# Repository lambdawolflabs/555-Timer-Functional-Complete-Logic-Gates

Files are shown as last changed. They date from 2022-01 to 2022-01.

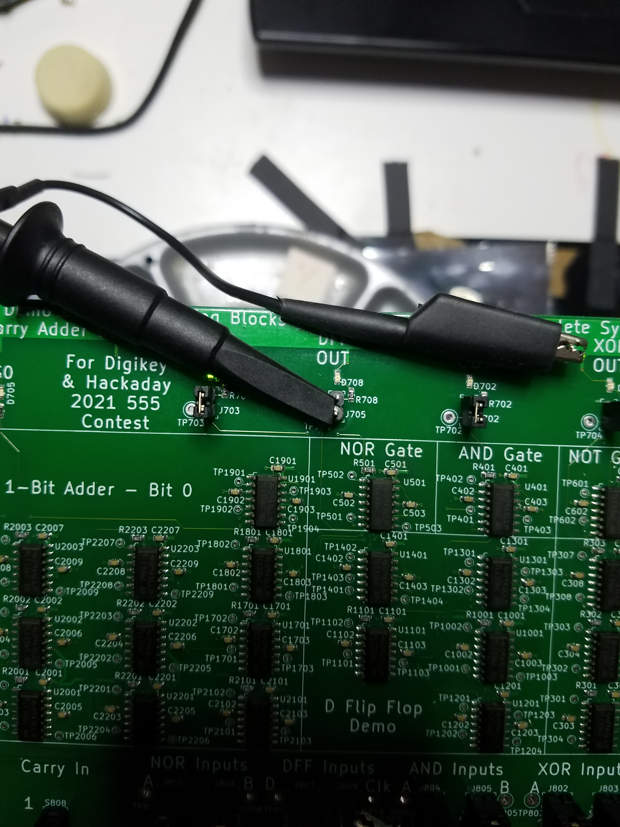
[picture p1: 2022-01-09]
Photos/DFF_PropTest_Setup_Output_20220109_155419.jpg

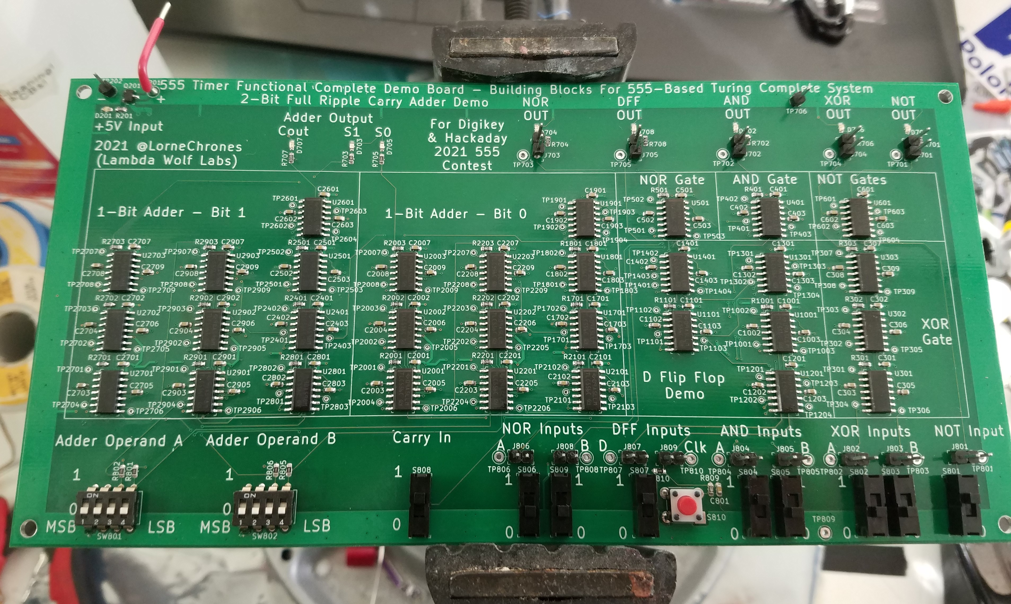
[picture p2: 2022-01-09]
Photos/Assembled_Board_Overview_Top_20220109_130825.jpg

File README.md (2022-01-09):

# 555-Timer-Functional-Complete-Logic-Gates

Hackaday IO Project Link Here (More details there): https://hackaday.io/project/183516 

For 2021/2022 Hackaday/Digikey 555 Timer Contest: https://hackaday.io/contest/182830-555-timer-contest

**
Overview:**
Purpose: 2 bit ripple-carry adder using nothing but 556s timer chips ( 2bits x (2 XORs + 2 ANDs + 1 OR = 6 + 6 + 2 + 2 + 3) ) = 38 555s or 19 556s. Inputs being dip switches and the outputs being LEDs. 

	A couple of spare 555s for demonstrating various gates individually:
		NOT - 1 555
		AND - 2 555
		NOR - 2 555
		XOR - 6 555
		D Flip Flop (Safe, not edge triggered)    -   Requires 7 555s?

Specs:

	-Room Temp Operation (25C +/-10C)
	-5VDC Operation (~180mA peak)
	-Powered by bench power supply with binding posts or hooks (reverse protection MOSFET included)
	-NO explicit ESD protection.

Logic Gate Ports:

	<FUNC>_<CMOS or NMOS>_<IN or OUT>_<Boolean Identifier: A B or Y or Q  or Abar  or  Bbar>   
	
	e.g.  AND_CMOS_IN_A   or    INV_CMOS_OUT_ABAR    or   A0_CMOS_IN
	Q is saved for Flip Flops, Y is saved for logic gates

Switches Ports:

	<FUNC>_<PD or PU or CMOS>_<SW or PB>

	e.g. A2_PD_SW  or  Carry_CMOS_SW  or AND_Demo_A_CMOS_SW

LED Ports:

	<FUNC>_<ActiveHigh or ActiveLow>_LED

	e.g. S3_ActiveHigh_LED

Labels:

	For highest level net name:  <FUNC>_Root  e.g. S0_Root  or Cout_Root

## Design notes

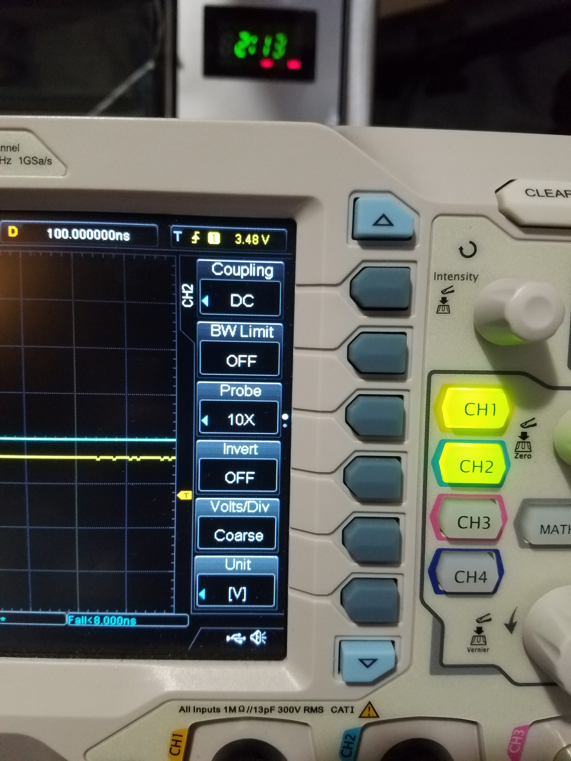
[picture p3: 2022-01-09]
Photos/ScopeChBSettings_20220109_153201.jpg

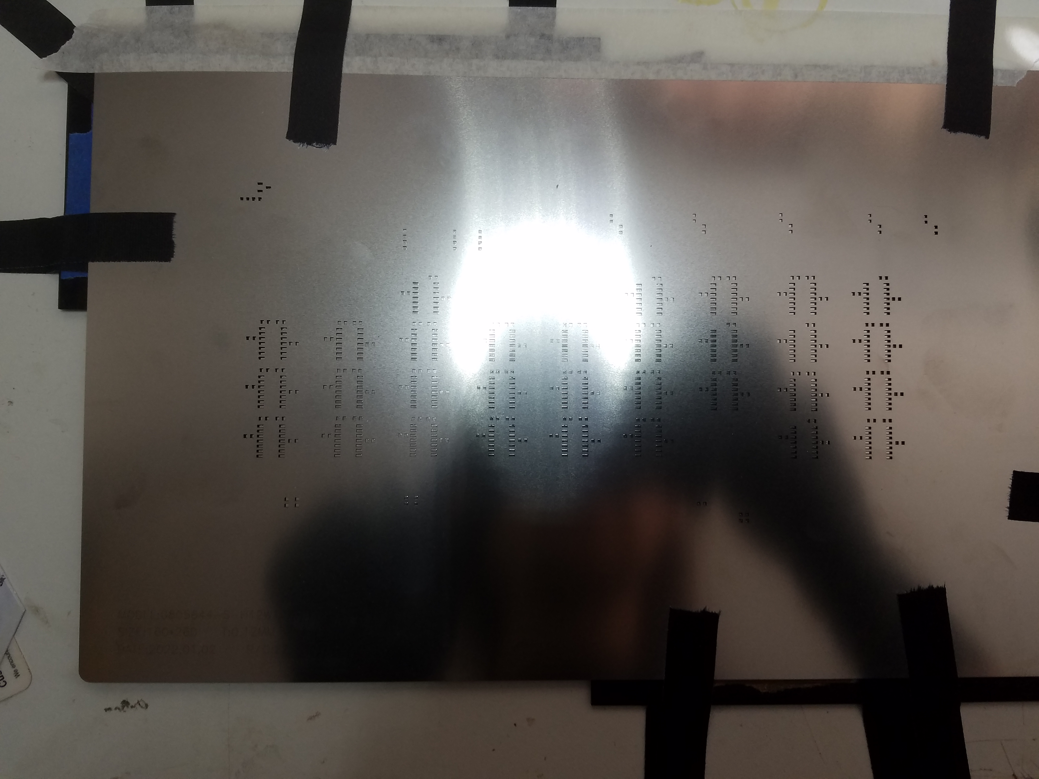
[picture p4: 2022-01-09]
Photos/ReadyForPaste_20220108_125551.jpg

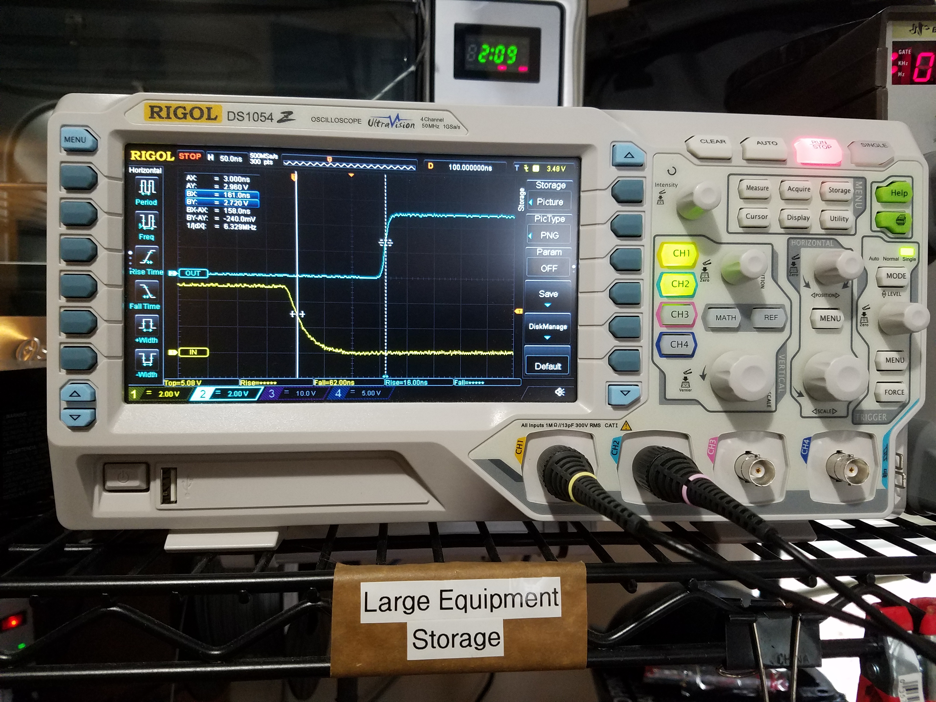
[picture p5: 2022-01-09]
Photos/Oscope_Used_20220109_152751.jpg

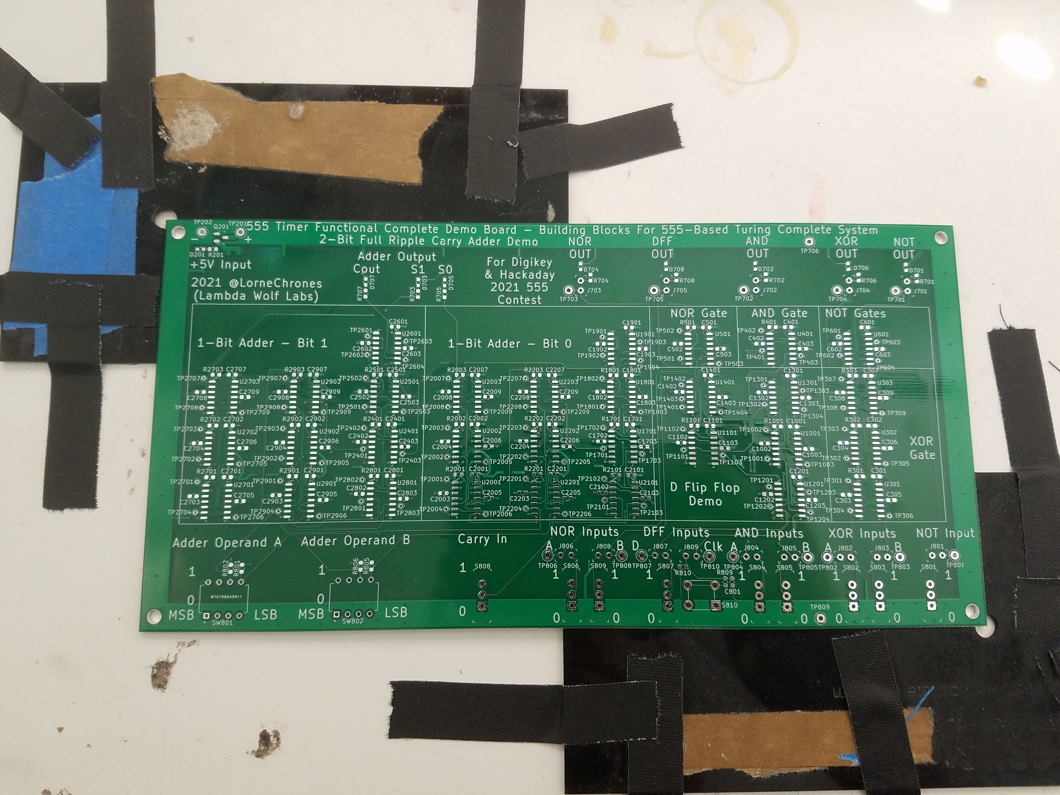
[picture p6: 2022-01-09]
Photos/BareBoard_20220108_125135.jpg

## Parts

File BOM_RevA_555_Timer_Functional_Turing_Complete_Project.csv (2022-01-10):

BOM/Design Name: | 555 Timer Functional Complete For Turing Machine Project
Drawing Number: | "/> 3
Revision: | A
Company: | Lambda Wolf Lab (Lorne Chrones)
Date: | 12/30/2021 5:45:50 PM
Tool: | Eeschema (5.1.2)-2
Populated Component Count: | 201
Number of DNP Components: | 0
Line Item | Ref | Qty | Value | Footprint | MPN | Manufacturer | Description | Datasheet | Vendor
1 | C301 | 1 | CL10B104KB8NNNL | Capacitor_SMD:C_0603_1608Metric | CL10B104KB8NNNL | Samsung Electro-Mechanics | CAP CER 0.1UF 50V X7R 0603 | http://www.samsungsem.com/kr/support/product-search/mlcc/CL10B104KB8NNNL.jsp
1 | C302 | 1 | CL10B104KB8NNNL | Capacitor_SMD:C_0603_1608Metric | CL10B104KB8NNNL | Samsung Electro-Mechanics | CAP CER 0.1UF 50V X7R 0603 | http://www.samsungsem.com/kr/support/product-search/mlcc/CL10B104KB8NNNL.jsp
1 | C303 | 1 | CL10B104KB8NNNL | Capacitor_SMD:C_0603_1608Metric | CL10B104KB8NNNL | Samsung Electro-Mechanics | CAP CER 0.1UF 50V X7R 0603 | http://www.samsungsem.com/kr/support/product-search/mlcc/CL10B104KB8NNNL.jsp
1 | C304 | 1 | CL10B104KB8NNNL | Capacitor_SMD:C_0603_1608Metric | CL10B104KB8NNNL | Samsung Electro-Mechanics | CAP CER 0.1UF 50V X7R 0603 | http://www.samsungsem.com/kr/support/product-search/mlcc/CL10B104KB8NNNL.jsp
1 | C305 | 1 | CL10B104KB8NNNL | Capacitor_SMD:C_0603_1608Metric | CL10B104KB8NNNL | Samsung Electro-Mechanics | CAP CER 0.1UF 50V X7R 0603 | http://www.samsungsem.com/kr/support/product-search/mlcc/CL10B104KB8NNNL.jsp
1 | C306 | 1 | CL10B104KB8NNNL | Capacitor_SMD:C_0603_1608Metric | CL10B104KB8NNNL | Samsung Electro-Mechanics | CAP CER 0.1UF 50V X7R 0603 | http://www.samsungsem.com/kr/support/product-search/mlcc/CL10B104KB8NNNL.jsp
1 | C307 | 1 | CL10B104KB8NNNL | Capacitor_SMD:C_0603_1608Metric | CL10B104KB8NNNL | Samsung Electro-Mechanics | CAP CER 0.1UF 50V X7R 0603 | http://www.samsungsem.com/kr/support/product-search/mlcc/CL10B104KB8NNNL.jsp
1 | C308 | 1 | CL10B104KB8NNNL | Capacitor_SMD:C_0603_1608Metric | CL10B104KB8NNNL | Samsung Electro-Mechanics | CAP CER 0.1UF 50V X7R 0603 | http://www.samsungsem.com/kr/support/product-search/mlcc/CL10B104KB8NNNL.jsp
1 | C309 | 1 | CL10B104KB8NNNL | Capacitor_SMD:C_0603_1608Metric | CL10B104KB8NNNL | Samsung Electro-Mechanics | CAP CER 0.1UF 50V X7R 0603 | http://www.samsungsem.com/kr/support/product-search/mlcc/CL10B104KB8NNNL.jsp
1 | C401 | 1 | CL10B104KB8NNNL | Capacitor_SMD:C_0603_1608Metric | CL10B104KB8NNNL | Samsung Electro-Mechanics | CAP CER 0.1UF 50V X7R 0603 | http://www.samsungsem.com/kr/support/product-search/mlcc/CL10B104KB8NNNL.jsp
1 | C402 | 1 | CL10B104KB8NNNL | Capacitor_SMD:C_0603_1608Metric | CL10B104KB8NNNL | Samsung Electro-Mechanics | CAP CER 0.1UF 50V X7R 0603 | http://www.samsungsem.com/kr/support/product-search/mlcc/CL10B104KB8NNNL.jsp
1 | C403 | 1 | CL10B104KB8NNNL | Capacitor_SMD:C_0603_1608Metric | CL10B104KB8NNNL | Samsung Electro-Mechanics | CAP CER 0.1UF 50V X7R 0603 | http://www.samsungsem.com/kr/support/product-search/mlcc/CL10B104KB8NNNL.jsp
1 | C501 | 1 | CL10B104KB8NNNL | Capacitor_SMD:C_0603_1608Metric | CL10B104KB8NNNL | Samsung Electro-Mechanics | CAP CER 0.1UF 50V X7R 0603 | http://www.samsungsem.com/kr/support/product-search/mlcc/CL10B104KB8NNNL.jsp
1 | C502 | 1 | CL10B104KB8NNNL | Capacitor_SMD:C_0603_1608Metric | CL10B104KB8NNNL | Samsung Electro-Mechanics | CAP CER 0.1UF 50V X7R 0603 | http://www.samsungsem.com/kr/support/product-search/mlcc/CL10B104KB8NNNL.jsp
1 | C503 | 1 | CL10B104KB8NNNL | Capacitor_SMD:C_0603_1608Metric | CL10B104KB8NNNL | Samsung Electro-Mechanics | CAP CER 0.1UF 50V X7R 0603 | http://www.samsungsem.com/kr/support/product-search/mlcc/CL10B104KB8NNNL.jsp
1 | C601 | 1 | CL10B104KB8NNNL | Capacitor_SMD:C_0603_1608Metric | CL10B104KB8NNNL | Samsung Electro-Mechanics | CAP CER 0.1UF 50V X7R 0603 | http://www.samsungsem.com/kr/support/product-search/mlcc/CL10B104KB8NNNL.jsp
1 | C602 | 1 | CL10B104KB8NNNL | Capacitor_SMD:C_0603_1608Metric | CL10B104KB8NNNL | Samsung Electro-Mechanics | CAP CER 0.1UF 50V X7R 0603 | http://www.samsungsem.com/kr/support/product-search/mlcc/CL10B104KB8NNNL.jsp
1 | C603 | 1 | CL10B104KB8NNNL | Capacitor_SMD:C_0603_1608Metric | CL10B104KB8NNNL | Samsung Electro-Mechanics | CAP CER 0.1UF 50V X7R 0603 | http://www.samsungsem.com/kr/support/product-search/mlcc/CL10B104KB8NNNL.jsp
1 | C801 | 1 | CL10B104KB8NNNL | Capacitor_SMD:C_0603_1608Metric | CL10B104KB8NNNL | Samsung Electro-Mechanics | CAP CER 0.1UF 50V X7R 0603 | http://www.samsungsem.com/kr/support/product-search/mlcc/CL10B104KB8NNNL.jsp
1 | C1001 | 1 | CL10B104KB8NNNL | Capacitor_SMD:C_0603_1608Metric | CL10B104KB8NNNL | Samsung Electro-Mechanics | CAP CER 0.1UF 50V X7R 0603 | http://www.samsungsem.com/kr/support/product-search/mlcc/CL10B104KB8NNNL.jsp
1 | C1002 | 1 | CL10B104KB8NNNL | Capacitor_SMD:C_0603_1608Metric | CL10B104KB8NNNL | Samsung Electro-Mechanics | CAP CER 0.1UF 50V X7R 0603 | http://www.samsungsem.com/kr/support/product-search/mlcc/CL10B104KB8NNNL.jsp
1 | C1003 | 1 | CL10B104KB8NNNL | Capacitor_SMD:C_0603_1608Metric | CL10B104KB8NNNL | Samsung Electro-Mechanics | CAP CER 0.1UF 50V X7R 0603 | http://www.samsungsem.com/kr/support/product-search/mlcc/CL10B104KB8NNNL.jsp
1 | C1101 | 1 | CL10B104KB8NNNL | Capacitor_SMD:C_0603_1608Metric | CL10B104KB8NNNL | Samsung Electro-Mechanics | CAP CER 0.1UF 50V X7R 0603 | http://www.samsungsem.com/kr/support/product-search/mlcc/CL10B104KB8NNNL.jsp
1 | C1102 | 1 | CL10B104KB8NNNL | Capacitor_SMD:C_0603_1608Metric | CL10B104KB8NNNL | Samsung Electro-Mechanics | CAP CER 0.1UF 50V X7R 0603 | http://www.samsungsem.com/kr/support/product-search/mlcc/CL10B104KB8NNNL.jsp
1 | C1103 | 1 | CL10B104KB8NNNL | Capacitor_SMD:C_0603_1608Metric | CL10B104KB8NNNL | Samsung Electro-Mechanics | CAP CER 0.1UF 50V X7R 0603 | http://www.samsungsem.com/kr/support/product-search/mlcc/CL10B104KB8NNNL.jsp
1 | C1201 | 1 | CL10B104KB8NNNL | Capacitor_SMD:C_0603_1608Metric | CL10B104KB8NNNL | Samsung Electro-Mechanics | CAP CER 0.1UF 50V X7R 0603 | http://www.samsungsem.com/kr/support/product-search/mlcc/CL10B104KB8NNNL.jsp
1 | C1202 | 1 | CL10B104KB8NNNL | Capacitor_SMD:C_0603_1608Metric | CL10B104KB8NNNL | Samsung Electro-Mechanics | CAP CER 0.1UF 50V X7R 0603 | http://www.samsungsem.com/kr/support/product-search/mlcc/CL10B104KB8NNNL.jsp
1 | C1203 | 1 | CL10B104KB8NNNL | Capacitor_SMD:C_0603_1608Metric | CL10B104KB8NNNL | Samsung Electro-Mechanics | CAP CER 0.1UF 50V X7R 0603 | http://www.samsungsem.com/kr/support/product-search/mlcc/CL10B104KB8NNNL.jsp
1 | C1301 | 1 | CL10B104KB8NNNL | Capacitor_SMD:C_0603_1608Metric | CL10B104KB8NNNL | Samsung Electro-Mechanics | CAP CER 0.1UF 50V X7R 0603 | http://www.samsungsem.com/kr/support/product-search/mlcc/CL10B104KB8NNNL.jsp
1 | C1302 | 1 | CL10B104KB8NNNL | Capacitor_SMD:C_0603_1608Metric | CL10B104KB8NNNL | Samsung Electro-Mechanics | CAP CER 0.1UF 50V X7R 0603 | http://www.samsungsem.com/kr/support/product-search/mlcc/CL10B104KB8NNNL.jsp
1 | C1303 | 1 | CL10B104KB8NNNL | Capacitor_SMD:C_0603_1608Metric | CL10B104KB8NNNL | Samsung Electro-Mechanics | CAP CER 0.1UF 50V X7R 0603 | http://www.samsungsem.com/kr/support/product-search/mlcc/CL10B104KB8NNNL.jsp
1 | C1401 | 1 | CL10B104KB8NNNL | Capacitor_SMD:C_0603_1608Metric | CL10B104KB8NNNL | Samsung Electro-Mechanics | CAP CER 0.1UF 50V X7R 0603 | http://www.samsungsem.com/kr/support/product-search/mlcc/CL10B104KB8NNNL.jsp
1 | C1402 | 1 | CL10B104KB8NNNL | Capacitor_SMD:C_0603_1608Metric | CL10B104KB8NNNL | Samsung Electro-Mechanics | CAP CER 0.1UF 50V X7R 0603 | http://www.samsungsem.com/kr/support/product-search/mlcc/CL10B104KB8NNNL.jsp
1 | C1403 | 1 | CL10B104KB8NNNL | Capacitor_SMD:C_0603_1608Metric | CL10B104KB8NNNL | Samsung Electro-Mechanics | CAP CER 0.1UF 50V X7R 0603 | http://www.samsungsem.com/kr/support/product-search/mlcc/CL10B104KB8NNNL.jsp
1 | C1701 | 1 | CL10B104KB8NNNL | Capacitor_SMD:C_0603_1608Metric | CL10B104KB8NNNL | Samsung Electro-Mechanics | CAP CER 0.1UF 50V X7R 0603 | http://www.samsungsem.com/kr/support/product-search/mlcc/CL10B104KB8NNNL.jsp
1 | C1702 | 1 | CL10B104KB8NNNL | Capacitor_SMD:C_0603_1608Metric | CL10B104KB8NNNL | Samsung Electro-Mechanics | CAP CER 0.1UF 50V X7R 0603 | http://www.samsungsem.com/kr/support/product-search/mlcc/CL10B104KB8NNNL.jsp
1 | C1703 | 1 | CL10B104KB8NNNL | Capacitor_SMD:C_0603_1608Metric | CL10B104KB8NNNL | Samsung Electro-Mechanics | CAP CER 0.1UF 50V X7R 0603 | http://www.samsungsem.com/kr/support/product-search/mlcc/CL10B104KB8NNNL.jsp
1 | C1801 | 1 | CL10B104KB8NNNL | Capacitor_SMD:C_0603_1608Metric | CL10B104KB8NNNL | Samsung Electro-Mechanics | CAP CER 0.1UF 50V X7R 0603 | http://www.samsungsem.com/kr/support/product-search/mlcc/CL10B104KB8NNNL.jsp
1 | C1802 | 1 | CL10B104KB8NNNL | Capacitor_SMD:C_0603_1608Metric | CL10B104KB8NNNL | Samsung Electro-Mechanics | CAP CER 0.1UF 50V X7R 0603 | http://www.samsungsem.com/kr/support/product-search/mlcc/CL10B104KB8NNNL.jsp
1 | C1803 | 1 | CL10B104KB8NNNL | Capacitor_SMD:C_0603_1608Metric | CL10B104KB8NNNL | Samsung Electro-Mechanics | CAP CER 0.1UF 50V X7R 0603 | http://www.samsungsem.com/kr/support/product-search/mlcc/CL10B104KB8NNNL.jsp
1 | C1901 | 1 | CL10B104KB8NNNL | Capacitor_SMD:C_0603_1608Metric | CL10B104KB8NNNL | Samsung Electro-Mechanics | CAP CER 0.1UF 50V X7R 0603 | http://www.samsungsem.com/kr/support/product-search/mlcc/CL10B104KB8NNNL.jsp
1 | C1902 | 1 | CL10B104KB8NNNL | Capacitor_SMD:C_0603_1608Metric | CL10B104KB8NNNL | Samsung Electro-Mechanics | CAP CER 0.1UF 50V X7R 0603 | http://www.samsungsem.com/kr/support/product-search/mlcc/CL10B104KB8NNNL.jsp
1 | C1903 | 1 | CL10B104KB8NNNL | Capacitor_SMD:C_0603_1608Metric | CL10B104KB8NNNL | Samsung Electro-Mechanics | CAP CER 0.1UF 50V X7R 0603 | http://www.samsungsem.com/kr/support/product-search/mlcc/CL10B104KB8NNNL.jsp
1 | C2001 | 1 | CL10B104KB8NNNL | Capacitor_SMD:C_0603_1608Metric | CL10B104KB8NNNL | Samsung Electro-Mechanics | CAP CER 0.1UF 50V X7R 0603 | http://www.samsungsem.com/kr/support/product-search/mlcc/CL10B104KB8NNNL.jsp
1 | C2002 | 1 | CL10B104KB8NNNL | Capacitor_SMD:C_0603_1608Metric | CL10B104KB8NNNL | Samsung Electro-Mechanics | CAP CER 0.1UF 50V X7R 0603 | http://www.samsungsem.com/kr/support/product-search/mlcc/CL10B104KB8NNNL.jsp
1 | C2003 | 1 | CL10B104KB8NNNL | Capacitor_SMD:C_0603_1608Metric | CL10B104KB8NNNL | Samsung Electro-Mechanics | CAP CER 0.1UF 50V X7R 0603 | http://www.samsungsem.com/kr/support/product-search/mlcc/CL10B104KB8NNNL.jsp
1 | C2004 | 1 | CL10B104KB8NNNL | Capacitor_SMD:C_0603_1608Metric | CL10B104KB8NNNL | Samsung Electro-Mechanics | CAP CER 0.1UF 50V X7R 0603 | http://www.samsungsem.com/kr/support/product-search/mlcc/CL10B104KB8NNNL.jsp
1 | C2005 | 1 | CL10B104KB8NNNL | Capacitor_SMD:C_0603_1608Metric | CL10B104KB8NNNL | Samsung Electro-Mechanics | CAP CER 0.1UF 50V X7R 0603 | http://www.samsungsem.com/kr/support/product-search/mlcc/CL10B104KB8NNNL.jsp
1 | C2006 | 1 | CL10B104KB8NNNL | Capacitor_SMD:C_0603_1608Metric | CL10B104KB8NNNL | Samsung Electro-Mechanics | CAP CER 0.1UF 50V X7R 0603 | http://www.samsungsem.com/kr/support/product-search/mlcc/CL10B104KB8NNNL.jsp
1 | C2007 | 1 | CL10B104KB8NNNL | Capacitor_SMD:C_0603_1608Metric | CL10B104KB8NNNL | Samsung Electro-Mechanics | CAP CER 0.1UF 50V X7R 0603 | http://www.samsungsem.com/kr/support/product-search/mlcc/CL10B104KB8NNNL.jsp
1 | C2008 | 1 | CL10B104KB8NNNL | Capacitor_SMD:C_0603_1608Metric | CL10B104KB8NNNL | Samsung Electro-Mechanics | CAP CER 0.1UF 50V X7R 0603 | http://www.samsungsem.com/kr/support/product-search/mlcc/CL10B104KB8NNNL.jsp
1 | C2009 | 1 | CL10B104KB8NNNL | Capacitor_SMD:C_0603_1608Metric | CL10B104KB8NNNL | Samsung Electro-Mechanics | CAP CER 0.1UF 50V X7R 0603 | http://www.samsungsem.com/kr/support/product-search/mlcc/CL10B104KB8NNNL.jsp
1 | C2101 | 1 | CL10B104KB8NNNL | Capacitor_SMD:C_0603_1608Metric | CL10B104KB8NNNL | Samsung Electro-Mechanics | CAP CER 0.1UF 50V X7R 0603 | http://www.samsungsem.com/kr/support/product-search/mlcc/CL10B104KB8NNNL.jsp
1 | C2102 | 1 | CL10B104KB8NNNL | Capacitor_SMD:C_0603_1608Metric | CL10B104KB8NNNL | Samsung Electro-Mechanics | CAP CER 0.1UF 50V X7R 0603 | http://www.samsungsem.com/kr/support/product-search/mlcc/CL10B104KB8NNNL.jsp
1 | C2103 | 1 | CL10B104KB8NNNL | Capacitor_SMD:C_0603_1608Metric | CL10B104KB8NNNL | Samsung Electro-Mechanics | CAP CER 0.1UF 50V X7R 0603 | http://www.samsungsem.com/kr/support/product-search/mlcc/CL10B104KB8NNNL.jsp
1 | C2201 | 1 | CL10B104KB8NNNL | Capacitor_SMD:C_0603_1608Metric | CL10B104KB8NNNL | Samsung Electro-Mechanics | CAP CER 0.1UF 50V X7R 0603 | http://www.samsungsem.com/kr/support/product-search/mlcc/CL10B104KB8NNNL.jsp
1 | C2202 | 1 | CL10B104KB8NNNL | Capacitor_SMD:C_0603_1608Metric | CL10B104KB8NNNL | Samsung Electro-Mechanics | CAP CER 0.1UF 50V X7R 0603 | http://www.samsungsem.com/kr/support/product-search/mlcc/CL10B104KB8NNNL.jsp
1 | C2203 | 1 | CL10B104KB8NNNL | Capacitor_SMD:C_0603_1608Metric | CL10B104KB8NNNL | Samsung Electro-Mechanics | CAP CER 0.1UF 50V X7R 0603 | http://www.samsungsem.com/kr/support/product-search/mlcc/CL10B104KB8NNNL.jsp
1 | C2204 | 1 | CL10B104KB8NNNL | Capacitor_SMD:C_0603_1608Metric | CL10B104KB8NNNL | Samsung Electro-Mechanics | CAP CER 0.1UF 50V X7R 0603 | http://www.samsungsem.com/kr/support/product-search/mlcc/CL10B104KB8NNNL.jsp
1 | C2205 | 1 | CL10B104KB8NNNL | Capacitor_SMD:C_0603_1608Metric | CL10B104KB8NNNL | Samsung Electro-Mechanics | CAP CER 0.1UF 50V X7R 0603 | http://www.samsungsem.com/kr/support/product-search/mlcc/CL10B104KB8NNNL.jsp
1 | C2206 | 1 | CL10B104KB8NNNL | Capacitor_SMD:C_0603_1608Metric | CL10B104KB8NNNL | Samsung Electro-Mechanics | CAP CER 0.1UF 50V X7R 0603 | http://www.samsungsem.com/kr/support/product-search/mlcc/CL10B104KB8NNNL.jsp
1 | C2207 | 1 | CL10B104KB8NNNL | Capacitor_SMD:C_0603_1608Metric | CL10B104KB8NNNL | Samsung Electro-Mechanics | CAP CER 0.1UF 50V X7R 0603 | http://www.samsungsem.com/kr/support/product-search/mlcc/CL10B104KB8NNNL.jsp
1 | C2208 | 1 | CL10B104KB8NNNL | Capacitor_SMD:C_0603_1608Metric | CL10B104KB8NNNL | Samsung Electro-Mechanics | CAP CER 0.1UF 50V X7R 0603 | http://www.samsungsem.com/kr/support/product-search/mlcc/CL10B104KB8NNNL.jsp
1 | C2209 | 1 | CL10B104KB8NNNL | Capacitor_SMD:C_0603_1608Metric | CL10B104KB8NNNL | Samsung Electro-Mechanics | CAP CER 0.1UF 50V X7R 0603 | http://www.samsungsem.com/kr/support/product-search/mlcc/CL10B104KB8NNNL.jsp
1 | C2401 | 1 | CL10B104KB8NNNL | Capacitor_SMD:C_0603_1608Metric | CL10B104KB8NNNL | Samsung Electro-Mechanics | CAP CER 0.1UF 50V X7R 0603 | http://www.samsungsem.com/kr/support/product-search/mlcc/CL10B104KB8NNNL.jsp
1 | C2402 | 1 | CL10B104KB8NNNL | Capacitor_SMD:C_0603_1608Metric | CL10B104KB8NNNL | Samsung Electro-Mechanics | CAP CER 0.1UF 50V X7R 0603 | http://www.samsungsem.com/kr/support/product-search/mlcc/CL10B104KB8NNNL.jsp
1 | C2403 | 1 | CL10B104KB8NNNL | Capacitor_SMD:C_0603_1608Metric | CL10B104KB8NNNL | Samsung Electro-Mechanics | CAP CER 0.1UF 50V X7R 0603 | http://www.samsungsem.com/kr/support/product-search/mlcc/CL10B104KB8NNNL.jsp
1 | C2501 | 1 | CL10B104KB8NNNL | Capacitor_SMD:C_0603_1608Metric | CL10B104KB8NNNL | Samsung Electro-Mechanics | CAP CER 0.1UF 50V X7R 0603 | http://www.samsungsem.com/kr/support/product-search/mlcc/CL10B104KB8NNNL.jsp
1 | C2502 | 1 | CL10B104KB8NNNL | Capacitor_SMD:C_0603_1608Metric | CL10B104KB8NNNL | Samsung Electro-Mechanics | CAP CER 0.1UF 50V X7R 0603 | http://www.samsungsem.com/kr/support/product-search/mlcc/CL10B104KB8NNNL.jsp
1 | C2503 | 1 | CL10B104KB8NNNL | Capacitor_SMD:C_0603_1608Metric | CL10B104KB8NNNL | Samsung Electro-Mechanics | CAP CER 0.1UF 50V X7R 0603 | http://www.samsungsem.com/kr/support/product-search/mlcc/CL10B104KB8NNNL.jsp
1 | C2601 | 1 | CL10B104KB8NNNL | Capacitor_SMD:C_0603_1608Metric | CL10B104KB8NNNL | Samsung Electro-Mechanics | CAP CER 0.1UF 50V X7R 0603 | http://www.samsungsem.com/kr/support/product-search/mlcc/CL10B104KB8NNNL.jsp
1 | C2602 | 1 | CL10B104KB8NNNL | Capacitor_SMD:C_0603_1608Metric | CL10B104KB8NNNL | Samsung Electro-Mechanics | CAP CER 0.1UF 50V X7R 0603 | http://www.samsungsem.com/kr/support/product-search/mlcc/CL10B104KB8NNNL.jsp
1 | C2603 | 1 | CL10B104KB8NNNL | Capacitor_SMD:C_0603_1608Metric | CL10B104KB8NNNL | Samsung Electro-Mechanics | CAP CER 0.1UF 50V X7R 0603 | http://www.samsungsem.com/kr/support/product-search/mlcc/CL10B104KB8NNNL.jsp
1 | C2701 | 1 | CL10B104KB8NNNL | Capacitor_SMD:C_0603_1608Metric | CL10B104KB8NNNL | Samsung Electro-Mechanics | CAP CER 0.1UF 50V X7R 0603 | http://www.samsungsem.com/kr/support/product-search/mlcc/CL10B104KB8NNNL.jsp
1 | C2702 | 1 | CL10B104KB8NNNL | Capacitor_SMD:C_0603_1608Metric | CL10B104KB8NNNL | Samsung Electro-Mechanics | CAP CER 0.1UF 50V X7R 0603 | http://www.samsungsem.com/kr/support/product-search/mlcc/CL10B104KB8NNNL.jsp
1 | C2703 | 1 | CL10B104KB8NNNL | Capacitor_SMD:C_0603_1608Metric | CL10B104KB8NNNL | Samsung Electro-Mechanics | CAP CER 0.1UF 50V X7R 0603 | http://www.samsungsem.com/kr/support/product-search/mlcc/CL10B104KB8NNNL.jsp
1 | C2704 | 1 | CL10B104KB8NNNL | Capacitor_SMD:C_0603_1608Metric | CL10B104KB8NNNL | Samsung Electro-Mechanics | CAP CER 0.1UF 50V X7R 0603 | http://www.samsungsem.com/kr/support/product-search/mlcc/CL10B104KB8NNNL.jsp
1 | C2705 | 1 | CL10B104KB8NNNL | Capacitor_SMD:C_0603_1608Metric | CL10B104KB8NNNL | Samsung Electro-Mechanics | CAP CER 0.1UF 50V X7R 0603 | http://www.samsungsem.com/kr/support/product-search/mlcc/CL10B104KB8NNNL.jsp
1 | C2706 | 1 | CL10B104KB8NNNL | Capacitor_SMD:C_0603_1608Metric | CL10B104KB8NNNL | Samsung Electro-Mechanics | CAP CER 0.1UF 50V X7R 0603 | http://www.samsungsem.com/kr/support/product-search/mlcc/CL10B104KB8NNNL.jsp
1 | C2707 | 1 | CL10B104KB8NNNL | Capacitor_SMD:C_0603_1608Metric | CL10B104KB8NNNL | Samsung Electro-Mechanics | CAP CER 0.1UF 50V X7R 0603 | http://www.samsungsem.com/kr/support/product-search/mlcc/CL10B104KB8NNNL.jsp
1 | C2708 | 1 | CL10B104KB8NNNL | Capacitor_SMD:C_0603_1608Metric | CL10B104KB8NNNL | Samsung Electro-Mechanics | CAP CER 0.1UF 50V X7R 0603 | http://www.samsungsem.com/kr/support/product-search/mlcc/CL10B104KB8NNNL.jsp
1 | C2709 | 1 | CL10B104KB8NNNL | Capacitor_SMD:C_0603_1608Metric | CL10B104KB8NNNL | Samsung Electro-Mechanics | CAP CER 0.1UF 50V X7R 0603 | http://www.samsungsem.com/kr/support/product-search/mlcc/CL10B104KB8NNNL.jsp
1 | C2801 | 1 | CL10B104KB8NNNL | Capacitor_SMD:C_0603_1608Metric | CL10B104KB8NNNL | Samsung Electro-Mechanics | CAP CER 0.1UF 50V X7R 0603 | http://www.samsungsem.com/kr/support/product-search/mlcc/CL10B104KB8NNNL.jsp
1 | C2802 | 1 | CL10B104KB8NNNL | Capacitor_SMD:C_0603_1608Metric | CL10B104KB8NNNL | Samsung Electro-Mechanics | CAP CER 0.1UF 50V X7R 0603 | http://www.samsungsem.com/kr/support/product-search/mlcc/CL10B104KB8NNNL.jsp
1 | C2803 | 1 | CL10B104KB8NNNL | Capacitor_SMD:C_0603_1608Metric | CL10B104KB8NNNL | Samsung Electro-Mechanics | CAP CER 0.1UF 50V X7R 0603 | http://www.samsungsem.com/kr/support/product-search/mlcc/CL10B104KB8NNNL.jsp
1 | C2901 | 1 | CL10B104KB8NNNL | Capacitor_SMD:C_0603_1608Metric | CL10B104KB8NNNL | Samsung Electro-Mechanics | CAP CER 0.1UF 50V X7R 0603 | http://www.samsungsem.com/kr/support/product-search/mlcc/CL10B104KB8NNNL.jsp
1 | C2902 | 1 | CL10B104KB8NNNL | Capacitor_SMD:C_0603_1608Metric | CL10B104KB8NNNL | Samsung Electro-Mechanics | CAP CER 0.1UF 50V X7R 0603 | http://www.samsungsem.com/kr/support/product-search/mlcc/CL10B104KB8NNNL.jsp
1 | C2903 | 1 | CL10B104KB8NNNL | Capacitor_SMD:C_0603_1608Metric | CL10B104KB8NNNL | Samsung Electro-Mechanics | CAP CER 0.1UF 50V X7R 0603 | http://www.samsungsem.com/kr/support/product-search/mlcc/CL10B104KB8NNNL.jsp
1 | C2904 | 1 | CL10B104KB8NNNL | Capacitor_SMD:C_0603_1608Metric | CL10B104KB8NNNL | Samsung Electro-Mechanics | CAP CER 0.1UF 50V X7R 0603 | http://www.samsungsem.com/kr/support/product-search/mlcc/CL10B104KB8NNNL.jsp
1 | C2905 | 1 | CL10B104KB8NNNL | Capacitor_SMD:C_0603_1608Metric | CL10B104KB8NNNL | Samsung Electro-Mechanics | CAP CER 0.1UF 50V X7R 0603 | http://www.samsungsem.com/kr/support/product-search/mlcc/CL10B104KB8NNNL.jsp
1 | C2906 | 1 | CL10B104KB8NNNL | Capacitor_SMD:C_0603_1608Metric | CL10B104KB8NNNL | Samsung Electro-Mechanics | CAP CER 0.1UF 50V X7R 0603 | http://www.samsungsem.com/kr/support/product-search/mlcc/CL10B104KB8NNNL.jsp
1 | C2907 | 1 | CL10B104KB8NNNL | Capacitor_SMD:C_0603_1608Metric | CL10B104KB8NNNL | Samsung Electro-Mechanics | CAP CER 0.1UF 50V X7R 0603 | http://www.samsungsem.com/kr/support/product-search/mlcc/CL10B104KB8NNNL.jsp
1 | C2908 | 1 | CL10B104KB8NNNL | Capacitor_SMD:C_0603_1608Metric | CL10B104KB8NNNL | Samsung Electro-Mechanics | CAP CER 0.1UF 50V X7R 0603 | http://www.samsungsem.com/kr/support/product-search/mlcc/CL10B104KB8NNNL.jsp
1 | C2909 | 1 | CL10B104KB8NNNL | Capacitor_SMD:C_0603_1608Metric | CL10B104KB8NNNL | Samsung Electro-Mechanics | CAP CER 0.1UF 50V X7R 0603 | http://www.samsungsem.com/kr/support/product-search/mlcc/CL10B104KB8NNNL.jsp
95 | D201 | 1 | 150060RS75000 | digikey-footprints:LED_0603 | 150060RS75000 | Wurth Electronics Inc. | LED RED CLEAR 0603 SMD | https://katalog.we-online.de/led/datasheet/150060RS75000.pdf
96 | D701 | 1 | 150060VS75000 | digikey-footprints:LED_0603 | 150060VS75000 | Wurth Electronics Inc. | LED GREEN CLEAR 0603 SMD | https://katalog.we-online.de/led/datasheet/150060VS75000.pdf
96 | D702 | 1 | 150060VS75000 | digikey-footprints:LED_0603 | 150060VS75000 | Wurth Electronics Inc. | LED GREEN CLEAR 0603 SMD | https://katalog.we-online.de/led/datasheet/150060VS75000.pdf
98 | D703 | 1 | 150060BS75000 | digikey-footprints:LED_0603 | 150060BS75000 | Wurth Electronics Inc. | LED BLUE CLEAR 0603 SMD | https://katalog.we-online.de/led/datasheet/150060BS75000.pdf
96 | D704 | 1 | 150060VS75000 | digikey-footprints:LED_0603 | 150060VS75000 | Wurth Electronics Inc. | LED GREEN CLEAR 0603 SMD | https://katalog.we-online.de/led/datasheet/150060VS75000.pdf
98 | D705 | 1 | 150060BS75000 | digikey-footprints:LED_0603 | 150060BS75000 | Wurth Electronics Inc. | LED BLUE CLEAR 0603 SMD | https://katalog.we-online.de/led/datasheet/150060BS75000.pdf
96 | D706 | 1 | 150060VS75000 | digikey-footprints:LED_0603 | 150060VS75000 | Wurth Electronics Inc. | LED GREEN CLEAR 0603 SMD | https://katalog.we-online.de/led/datasheet/150060VS75000.pdf
102 | D707 | 1 | 150060YS75000 | digikey-footprints:LED_0603 | 150060YS75000 | Wurth Electronics Inc. | LED YELLOW CLEAR 0603 SMD | https://katalog.we-online.de/led/datasheet/150060YS75000.pdf
96 | D708 | 1 | 150060VS75000 | digikey-footprints:LED_0603 | 150060VS75000 | Wurth Electronics Inc. | LED GREEN CLEAR 0603 SMD | https://katalog.we-online.de/led/datasheet/150060VS75000.pdf
104 | J701 | 1 | M20-9990246 | digikey-footprints:PinHeader_1x2_P2.54mm | M20-9990246 | Harwin Inc. | CONN HEADER VERT 2POS 2.54MM | https://cdn.harwin.com/pdfs/M20-999.pdf
104 | J702 | 1 | M20-9990246 | digikey-footprints:PinHeader_1x2_P2.54mm | M20-9990246 | Harwin Inc. | CONN HEADER VERT 2POS 2.54MM | https://cdn.harwin.com/pdfs/M20-999.pdf
104 | J703 | 1 | M20-9990246 | digikey-footprints:PinHeader_1x2_P2.54mm | M20-9990246 | Harwin Inc. | CONN HEADER VERT 2POS 2.54MM | https://cdn.harwin.com/pdfs/M20-999.pdf
104 | J704 | 1 | M20-9990246 | digikey-footprints:PinHeader_1x2_P2.54mm | M20-9990246 | Harwin Inc. | CONN HEADER VERT 2POS 2.54MM | https://cdn.harwin.com/pdfs/M20-999.pdf
104 | J705 | 1 | M20-9990246 | digikey-footprints:PinHeader_1x2_P2.54mm | M20-9990246 | Harwin Inc. | CONN HEADER VERT 2POS 2.54MM | https://cdn.harwin.com/pdfs/M20-999.pdf
104 | J801 | 1 | M20-9990246 | digikey-footprints:PinHeader_1x2_P2.54mm | M20-9990246 | Harwin Inc. | CONN HEADER VERT 2POS 2.54MM | https://cdn.harwin.com/pdfs/M20-999.pdf
104 | J802 | 1 | M20-9990246 | digikey-footprints:PinHeader_1x2_P2.54mm | M20-9990246 | Harwin Inc. | CONN HEADER VERT 2POS 2.54MM | https://cdn.harwin.com/pdfs/M20-999.pdf
104 | J803 | 1 | M20-9990246 | digikey-footprints:PinHeader_1x2_P2.54mm | M20-9990246 | Harwin Inc. | CONN HEADER VERT 2POS 2.54MM | https://cdn.harwin.com/pdfs/M20-999.pdf
104 | J804 | 1 | M20-9990246 | digikey-footprints:PinHeader_1x2_P2.54mm | M20-9990246 | Harwin Inc. | CONN HEADER VERT 2POS 2.54MM | https://cdn.harwin.com/pdfs/M20-999.pdf
104 | J805 | 1 | M20-9990246 | digikey-footprints:PinHeader_1x2_P2.54mm | M20-9990246 | Harwin Inc. | CONN HEADER VERT 2POS 2.54MM | https://cdn.harwin.com/pdfs/M20-999.pdf
104 | J806 | 1 | M20-9990246 | digikey-footprints:PinHeader_1x2_P2.54mm | M20-9990246 | Harwin Inc. | CONN HEADER VERT 2POS 2.54MM | https://cdn.harwin.com/pdfs/M20-999.pdf
104 | J807 | 1 | M20-9990246 | digikey-footprints:PinHeader_1x2_P2.54mm | M20-9990246 | Harwin Inc. | CONN HEADER VERT 2POS 2.54MM | https://cdn.harwin.com/pdfs/M20-999.pdf
104 | J808 | 1 | M20-9990246 | digikey-footprints:PinHeader_1x2_P2.54mm | M20-9990246 | Harwin Inc. | CONN HEADER VERT 2POS 2.54MM | https://cdn.harwin.com/pdfs/M20-999.pdf
104 | J809 | 1 | M20-9990246 | digikey-footprints:PinHeader_1x2_P2.54mm | M20-9990246 | Harwin Inc. | CONN HEADER VERT 2POS 2.54MM | https://cdn.harwin.com/pdfs/M20-999.pdf
118 | Q201 | 1 | AO3407A | digikey-footprints:SOT-23-3 | AO3407A | Alpha & Omega Semiconductor Inc. | MOSFET P-CH 30V 4.3A SOT23-3L | http://aosmd.com/res/data_sheets/AO3407A.pdf
119 | R201 | 1 | RC0603FR-071KL | Resistor_SMD:R_0603_1608Metric | RC0603FR-071KL | Yageo | RES SMD 1K OHM 1% 1/10W 0603 | http://www.yageo.com/documents/recent/PYu-RC_Group_51_RoHS_L_10.pdf
119 | R301 | 1 | RC0603FR-071KL | Resistor_SMD:R_0603_1608Metric | RC0603FR-071KL | Yageo | RES SMD 1K OHM 1% 1/10W 0603 | http://www.yageo.com/documents/recent/PYu-RC_Group_51_RoHS_L_10.pdf
119 | R302 | 1 | RC0603FR-071KL | Resistor_SMD:R_0603_1608Metric | RC0603FR-071KL | Yageo | RES SMD 1K OHM 1% 1/10W 0603 | http://www.yageo.com/documents/recent/PYu-RC_Group_51_RoHS_L_10.pdf
119 | R303 | 1 | RC0603FR-071KL | Resistor_SMD:R_0603_1608Metric | RC0603FR-071KL | Yageo | RES SMD 1K OHM 1% 1/10W 0603 | http://www.yageo.com/documents/recent/PYu-RC_Group_51_RoHS_L_10.pdf
119 | R401 | 1 | RC0603FR-071KL | Resistor_SMD:R_0603_1608Metric | RC0603FR-071KL | Yageo | RES SMD 1K OHM 1% 1/10W 0603 | http://www.yageo.com/documents/recent/PYu-RC_Group_51_RoHS_L_10.pdf
119 | R501 | 1 | RC0603FR-071KL | Resistor_SMD:R_0603_1608Metric | RC0603FR-071KL | Yageo | RES SMD 1K OHM 1% 1/10W 0603 | http://www.yageo.com/documents/recent/PYu-RC_Group_51_RoHS_L_10.pdf
125 | R701 | 1 | RC0603FR-07470RL | Resistor_SMD:R_0603_1608Metric | RC0603FR-07470RL | Yageo | RES 470 OHM 1% 1/10W 0603 | https://www.yageo.com/upload/media/product/productsearch/datasheet/rchip/PYu-RC_Group_51_RoHS_L_11.pdf
125 | R702 | 1 | RC0603FR-07470RL | Resistor_SMD:R_0603_1608Metric | RC0603FR-07470RL | Yageo | RES 470 OHM 1% 1/10W 0603 | https://www.yageo.com/upload/media/product/productsearch/datasheet/rchip/PYu-RC_Group_51_RoHS_L_11.pdf
127 | R703 | 1 | RMCF0603FT100R | Resistor_SMD:R_0603_1608Metric | RMCF0603FT100R | Stackpole Electronics Inc | RES 100 OHM 1% 1/10W 0603 | https://www.seielect.com/catalog/sei-rmcf_rmcp.pdf
125 | R704 | 1 | RC0603FR-07470RL | Resistor_SMD:R_0603_1608Metric | RC0603FR-07470RL | Yageo | RES 470 OHM 1% 1/10W 0603 | https://www.yageo.com/upload/media/product/productsearch/datasheet/rchip/PYu-RC_Group_51_RoHS_L_11.pdf
127 | R705 | 1 | RMCF0603FT100R | Resistor_SMD:R_0603_1608Metric | RMCF0603FT100R | Stackpole Electronics Inc | RES 100 OHM 1% 1/10W 0603 | https://www.seielect.com/catalog/sei-rmcf_rmcp.pdf
125 | R706 | 1 | RC0603FR-07470RL | Resistor_SMD:R_0603_1608Metric | RC0603FR-07470RL | Yageo | RES 470 OHM 1% 1/10W 0603 | https://www.yageo.com/upload/media/product/productsearch/datasheet/rchip/PYu-RC_Group_51_RoHS_L_11.pdf
119 | R707 | 1 | RC0603FR-071KL | Resistor_SMD:R_0603_1608Metric | RC0603FR-071KL | Yageo | RES SMD 1K OHM 1% 1/10W 0603 | http://www.yageo.com/documents/recent/PYu-RC_Group_51_RoHS_L_10.pdf
125 | R708 | 1 | RC0603FR-07470RL | Resistor_SMD:R_0603_1608Metric | RC0603FR-07470RL | Yageo | RES 470 OHM 1% 1/10W 0603 | https://www.yageo.com/upload/media/product/productsearch/datasheet/rchip/PYu-RC_Group_51_RoHS_L_11.pdf
133 | R801 | 1 | RMCF0603FT100K | Resistor_SMD:R_0603_1608Metric | RMCF0603FT100K | Stackpole | RES 100K OHM 1% 1/10W 0603 | https://www.seielect.com/catalog/sei-rmcf_rmcp.pdf
133 | R802 | 1 | RMCF0603FT100K | Resistor_SMD:R_0603_1608Metric | RMCF0603FT100K | Stackpole | RES 100K OHM 1% 1/10W 0603 | https://www.seielect.com/catalog/sei-rmcf_rmcp.pdf
133 | R805 | 1 | RMCF0603FT100K | Resistor_SMD:R_0603_1608Metric | RMCF0603FT100K | Stackpole | RES 100K OHM 1% 1/10W 0603 | https://www.seielect.com/catalog/sei-rmcf_rmcp.pdf
133 | R806 | 1 | RMCF0603FT100K | Resistor_SMD:R_0603_1608Metric | RMCF0603FT100K | Stackpole | RES 100K OHM 1% 1/10W 0603 | https://www.seielect.com/catalog/sei-rmcf_rmcp.pdf
119 | R809 | 1 | RC0603FR-071KL | Resistor_SMD:R_0603_1608Metric | RC0603FR-071KL | Yageo | RES SMD 1K OHM 1% 1/10W 0603 | http://www.yageo.com/documents/recent/PYu-RC_Group_51_RoHS_L_10.pdf
133 | R810 | 1 | RMCF0603FT100K | Resistor_SMD:R_0603_1608Metric | RMCF0603FT100K | Stackpole | RES 100K OHM 1% 1/10W 0603 | https://www.seielect.com/catalog/sei-rmcf_rmcp.pdf
119 | R1001 | 1 | RC0603FR-071KL | Resistor_SMD:R_0603_1608Metric | RC0603FR-071KL | Yageo | RES SMD 1K OHM 1% 1/10W 0603 | http://www.yageo.com/documents/recent/PYu-RC_Group_51_RoHS_L_10.pdf
119 | R1101 | 1 | RC0603FR-071KL | Resistor_SMD:R_0603_1608Metric | RC0603FR-071KL | Yageo | RES SMD 1K OHM 1% 1/10W 0603 | http://www.yageo.com/documents/recent/PYu-RC_Group_51_RoHS_L_10.pdf
119 | R1701 | 1 | RC0603FR-071KL | Resistor_SMD:R_0603_1608Metric | RC0603FR-071KL | Yageo | RES SMD 1K OHM 1% 1/10W 0603 | http://www.yageo.com/documents/recent/PYu-RC_Group_51_RoHS_L_10.pdf
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

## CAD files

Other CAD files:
Propagation Times Scope Shots/RISESETUP.stp
Propagation Times Scope Shots/FALLSETUP.stp

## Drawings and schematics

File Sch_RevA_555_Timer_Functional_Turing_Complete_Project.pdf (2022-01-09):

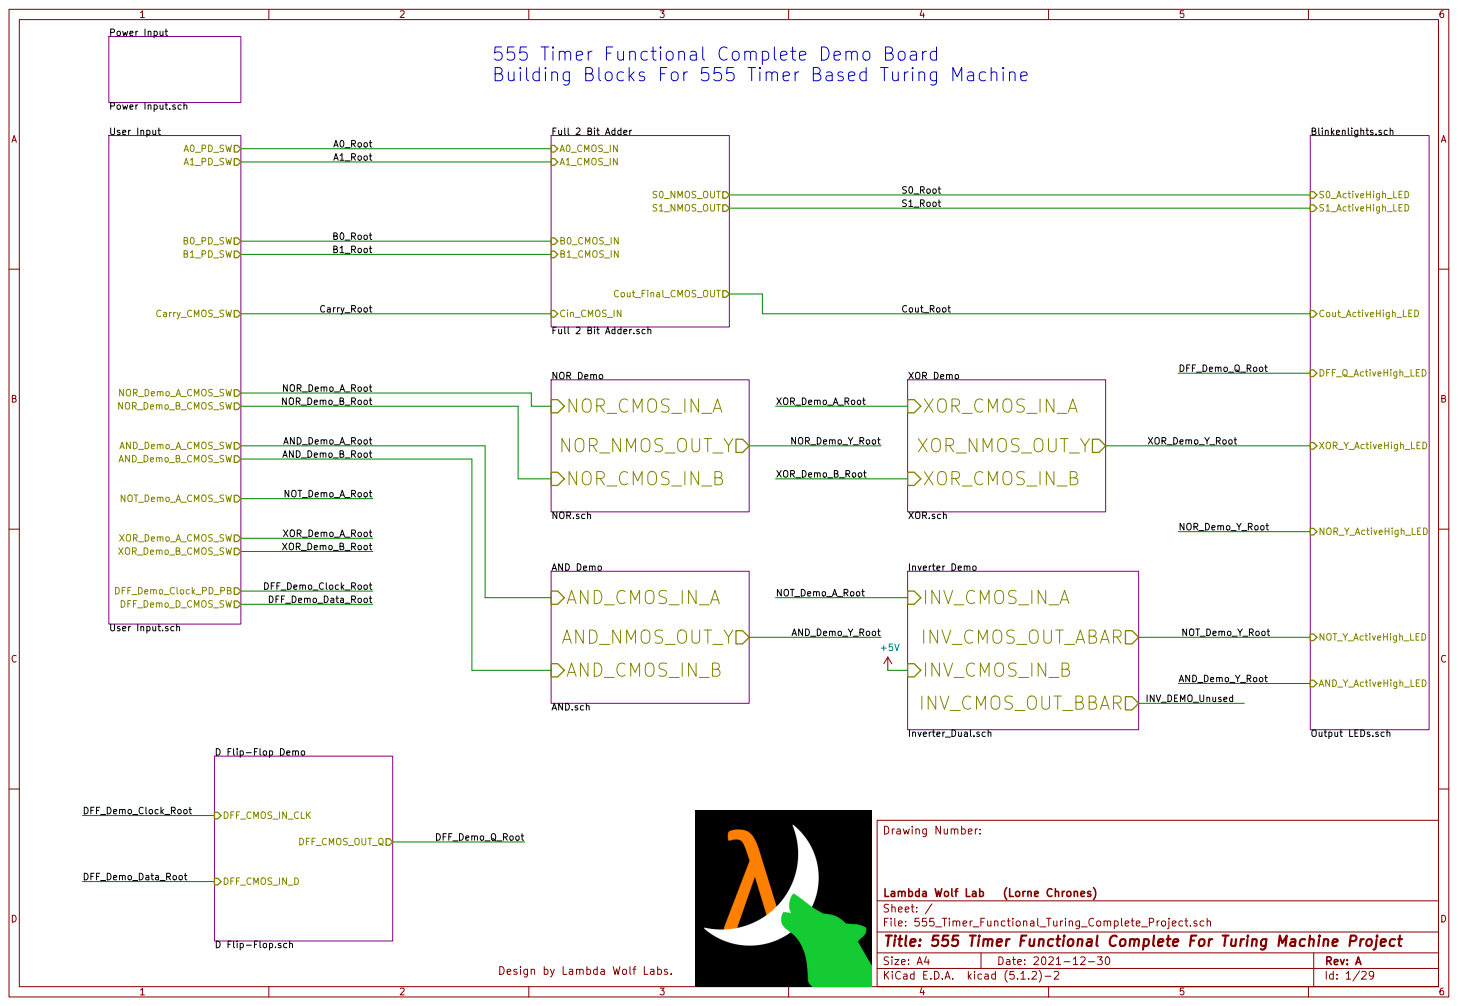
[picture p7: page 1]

555 Timer Functional Complete Demo Board
Building Blocks For 555 Timer Based Turing Machine
Full 2 Bit Adder Full 2 Bit Adder.sch A0_CMOS_IN

INV_DEMO_Unused NOR Demo NOR.sch NOR_CMOS_IN_A

AND Demo AND.sch AND_CMOS_IN_A

Id: 1/29 Title: 555 Timer Functional Complete For Turing Machine Project

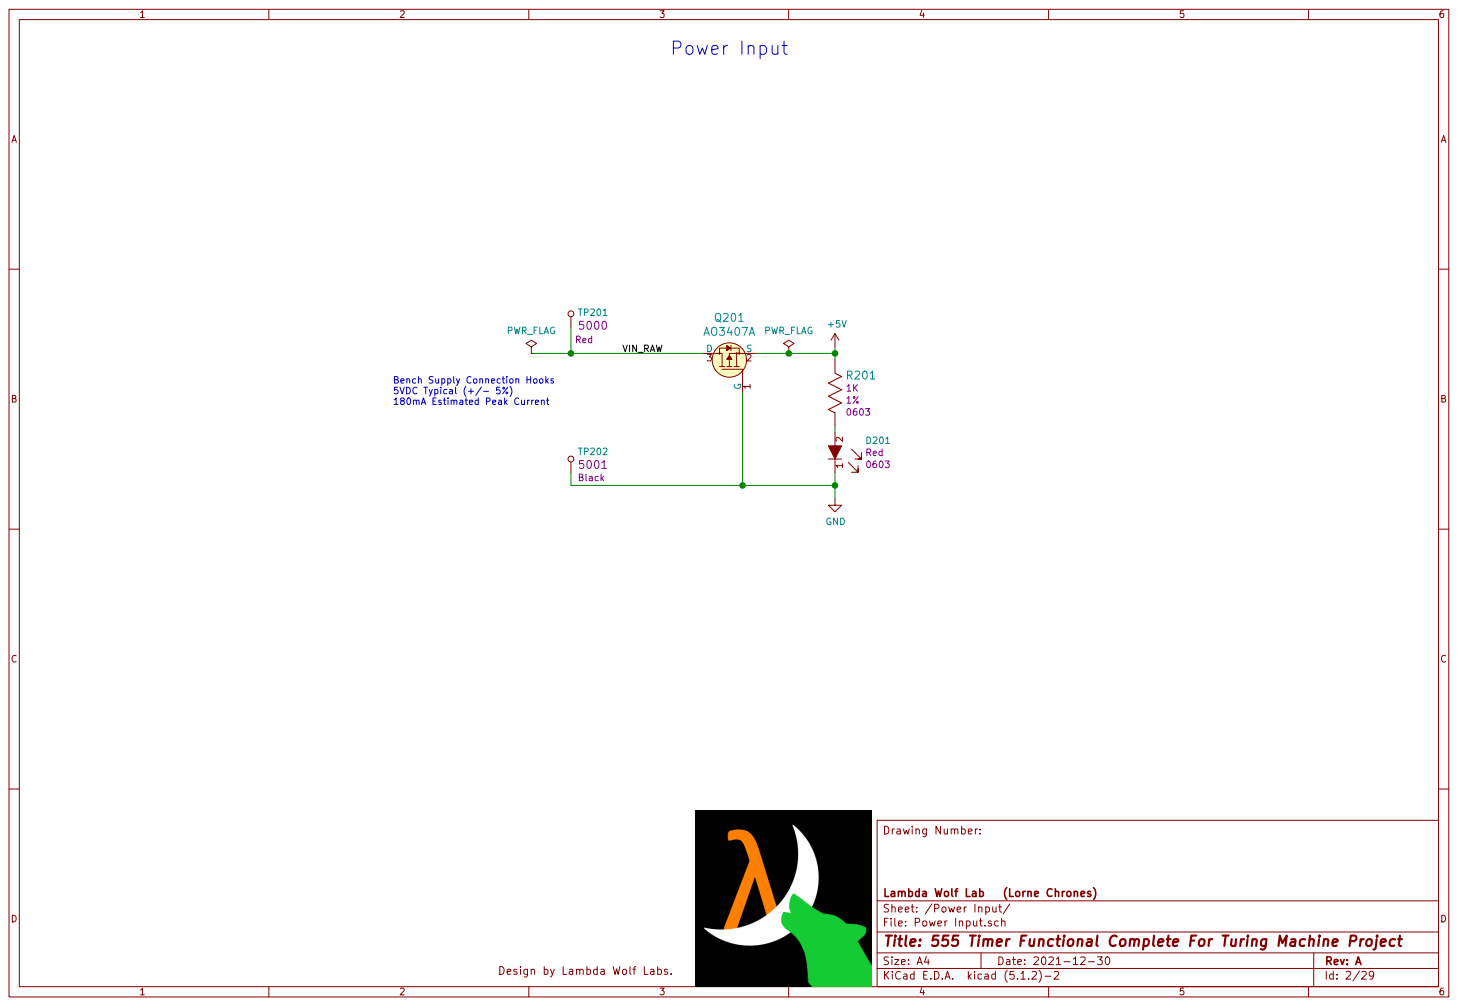
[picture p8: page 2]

Bench Supply Connection Hooks

Sheet: /Power Input/
File: Power Input.sch
Id: 2/29 Title: 555 Timer Functional Complete For Turing Machine Project

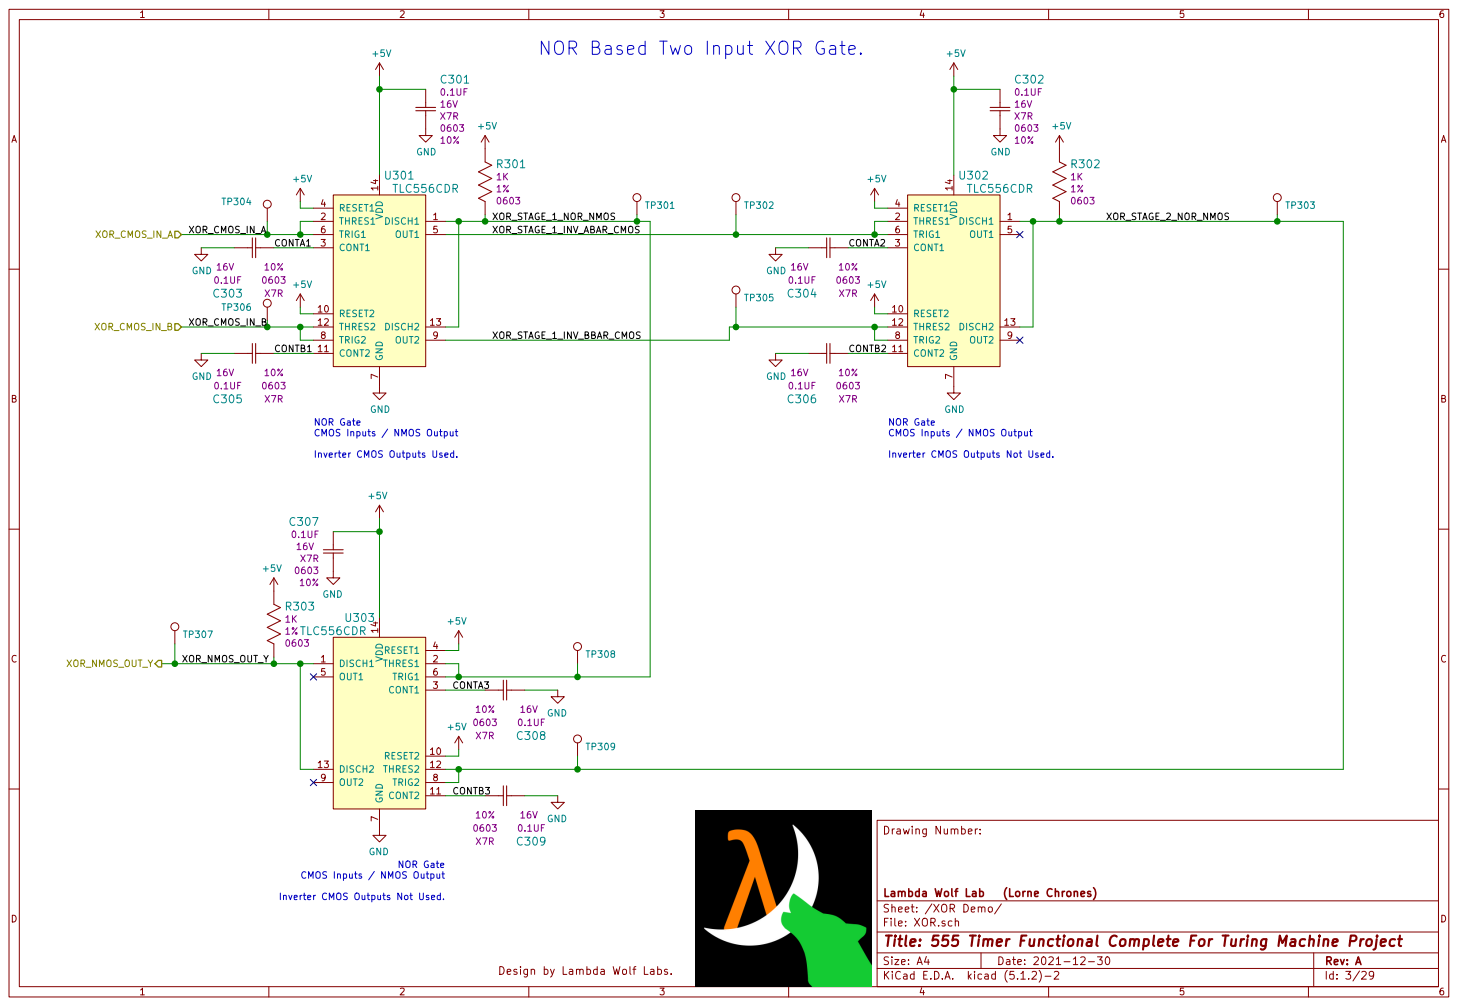
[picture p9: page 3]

+5V NOR Gate CMOS Inputs / NMOS Output

Inverter CMOS Outputs Not Used.

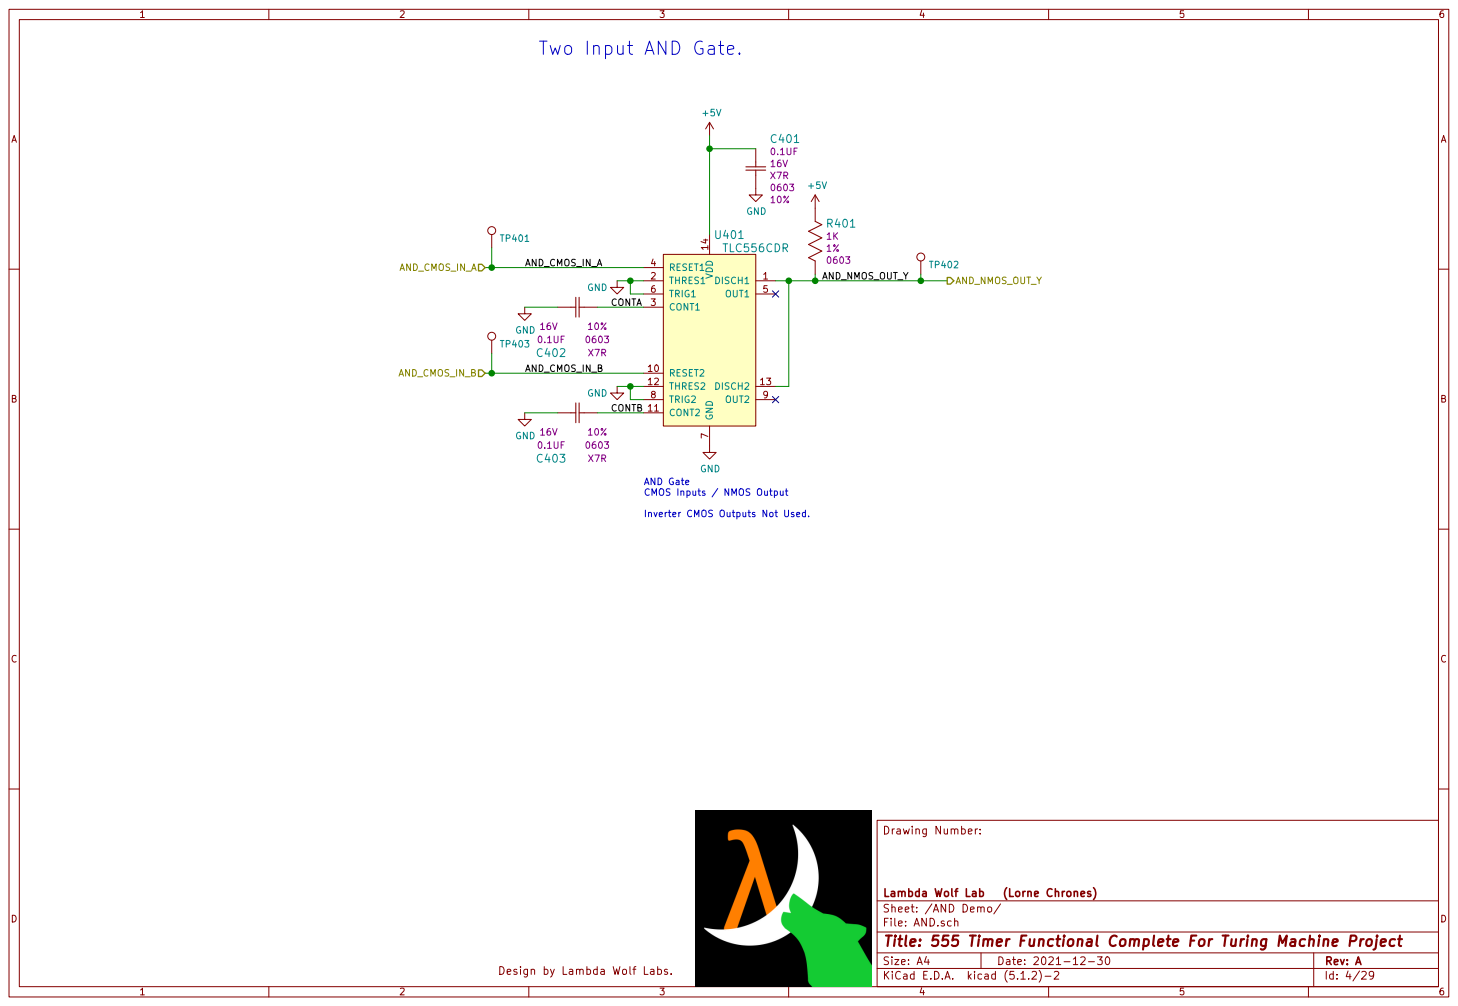
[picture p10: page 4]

AND Gate CMOS Inputs / NMOS Output

Id: 5/29 Title: 555 Timer Functional Complete For Turing Machine Project

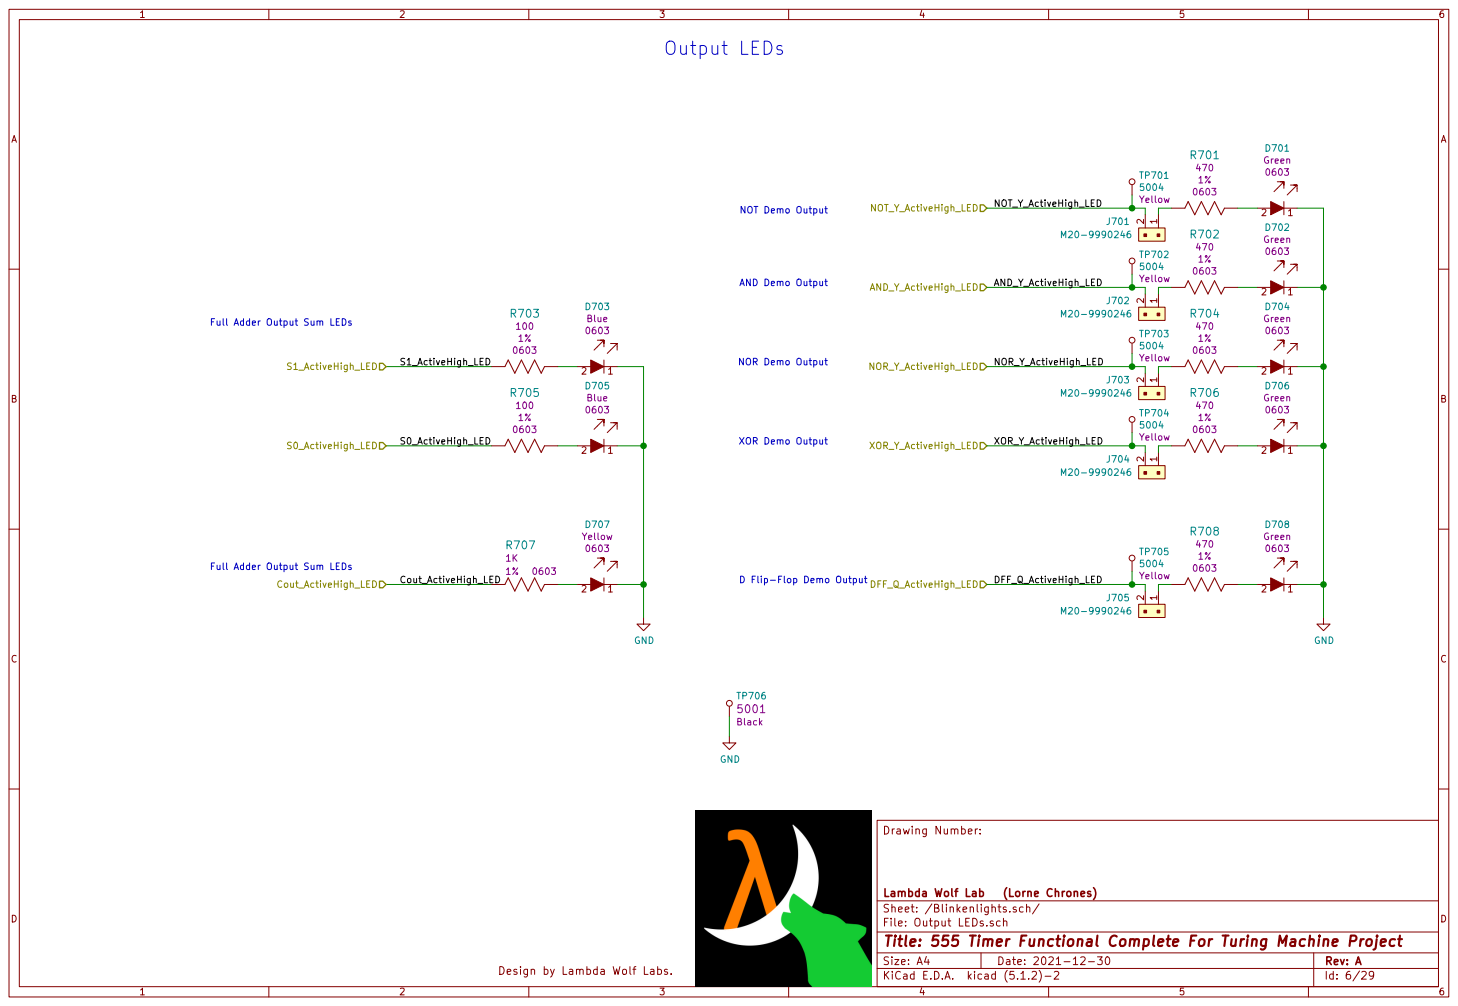
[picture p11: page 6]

Full Adder Output Sum LEDs

D Flip-Flop Demo Output TP706 5001

Sheet: /Blinkenlights.sch/
File: Output LEDs.sch
Id: 6/29 Title: 555 Timer Functional Complete For Turing Machine Project

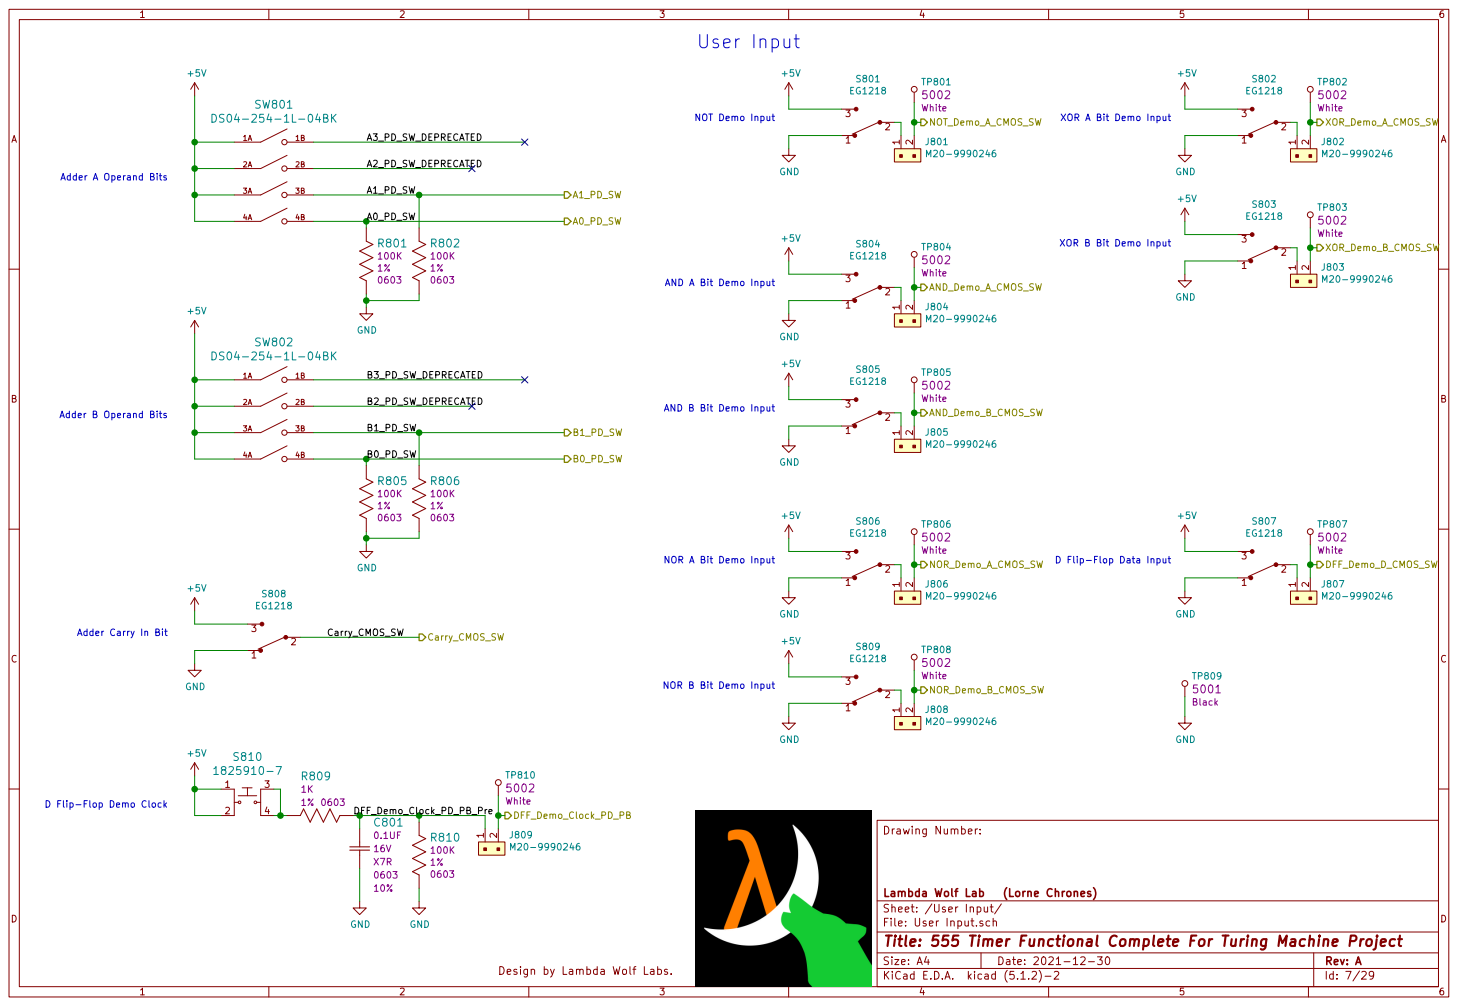
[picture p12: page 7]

Sheet: /User Input/
File: User Input.sch
Id: 7/29 Title: 555 Timer Functional Complete For Turing Machine Project

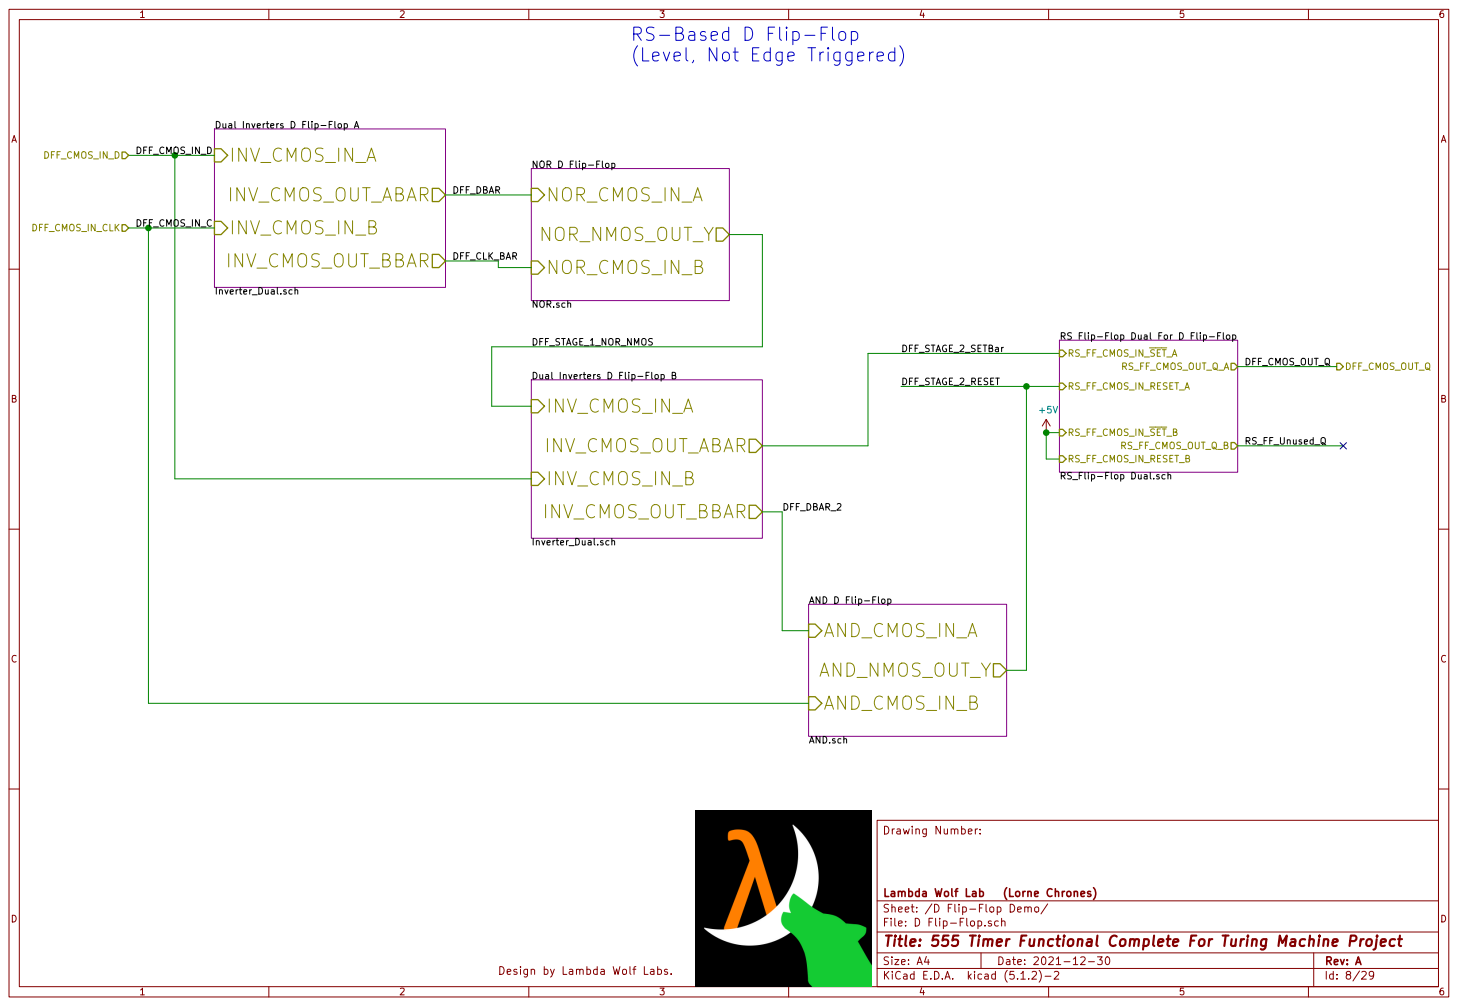
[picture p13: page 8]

(Level, Not Edge Triggered)

Dual Inverters D Flip-Flop A

NOR D Flip-Flop NOR.sch NOR_CMOS_IN_A

RS Flip-Flop Dual For D Flip-Flop

Dual Inverters D Flip-Flop B

AND D Flip-Flop AND.sch AND_CMOS_IN_A

Sheet: /D Flip-Flop Demo/
File: D Flip-Flop.sch
Id: 8/29 Title: 555 Timer Functional Complete For Turing Machine Project

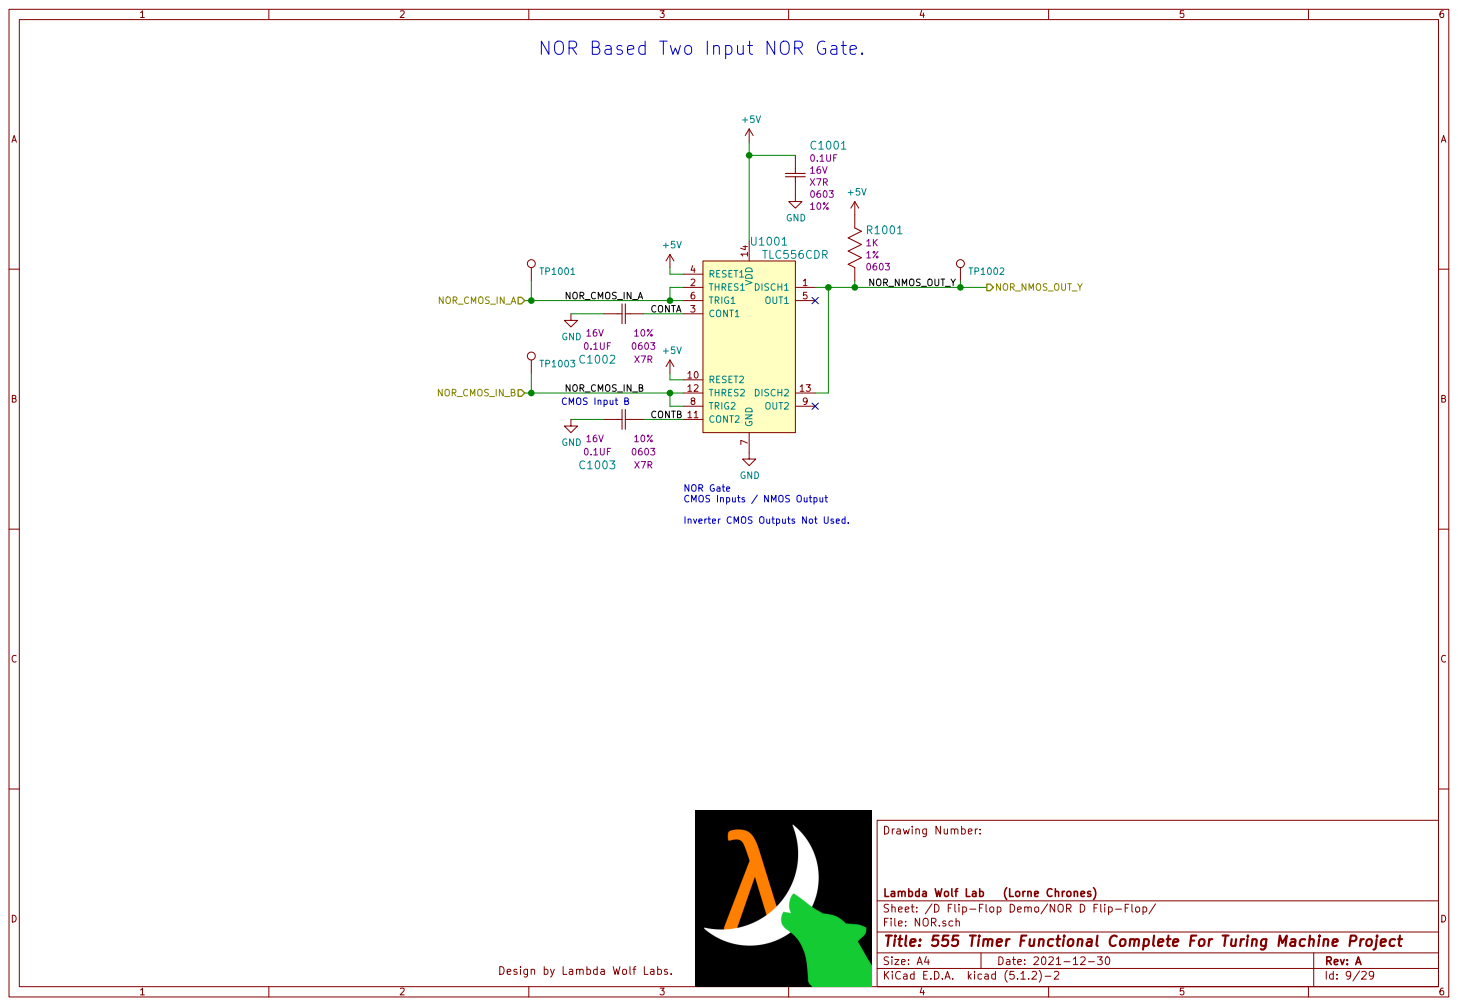
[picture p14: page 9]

Id: 9/29 Title: 555 Timer Functional Complete For Turing Machine Project File: NOR.sch Sheet: /D Flip-Flop Demo/NOR D Flip-Flop/

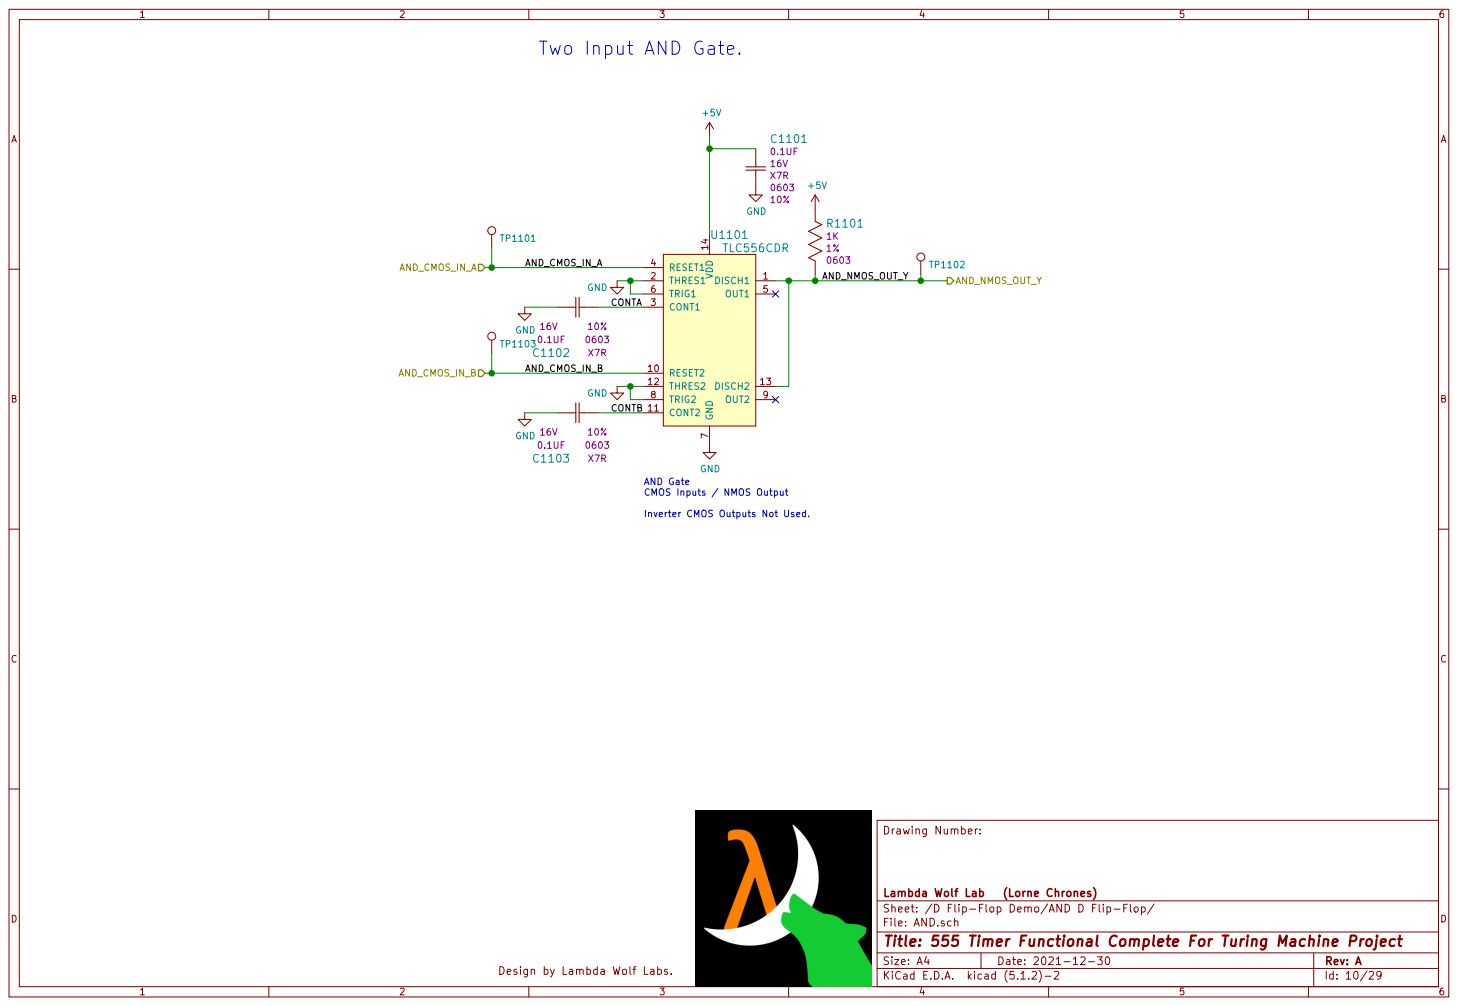
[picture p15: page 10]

AND Gate CMOS Inputs / NMOS Output

Id: 10/29 Title: 555 Timer Functional Complete For Turing Machine Project File: AND.sch Sheet: /D Flip-Flop Demo/AND D Flip-Flop/

Sheet: /D Flip-Flop Demo/Dual Inverters D Flip-Flop A/
File: Inverter_Dual.sch
Id: 11/29 Title: 555 Timer Functional Complete For Turing Machine Project

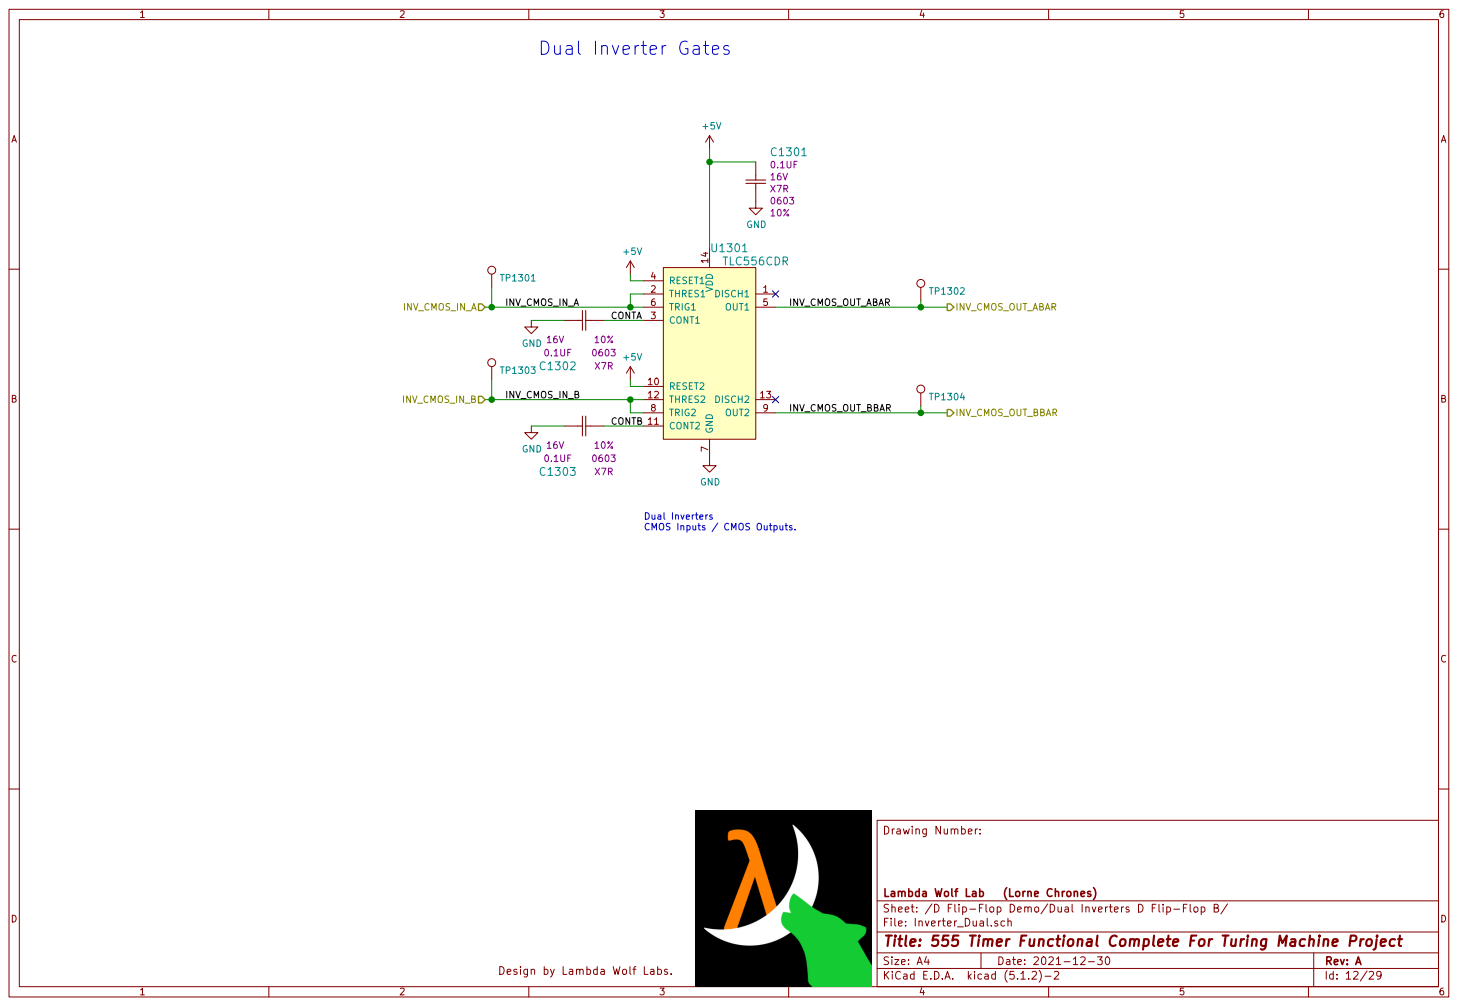
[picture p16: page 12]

Sheet: /D Flip-Flop Demo/Dual Inverters D Flip-Flop B/
File: Inverter_Dual.sch
Id: 12/29 Title: 555 Timer Functional Complete For Turing Machine Project

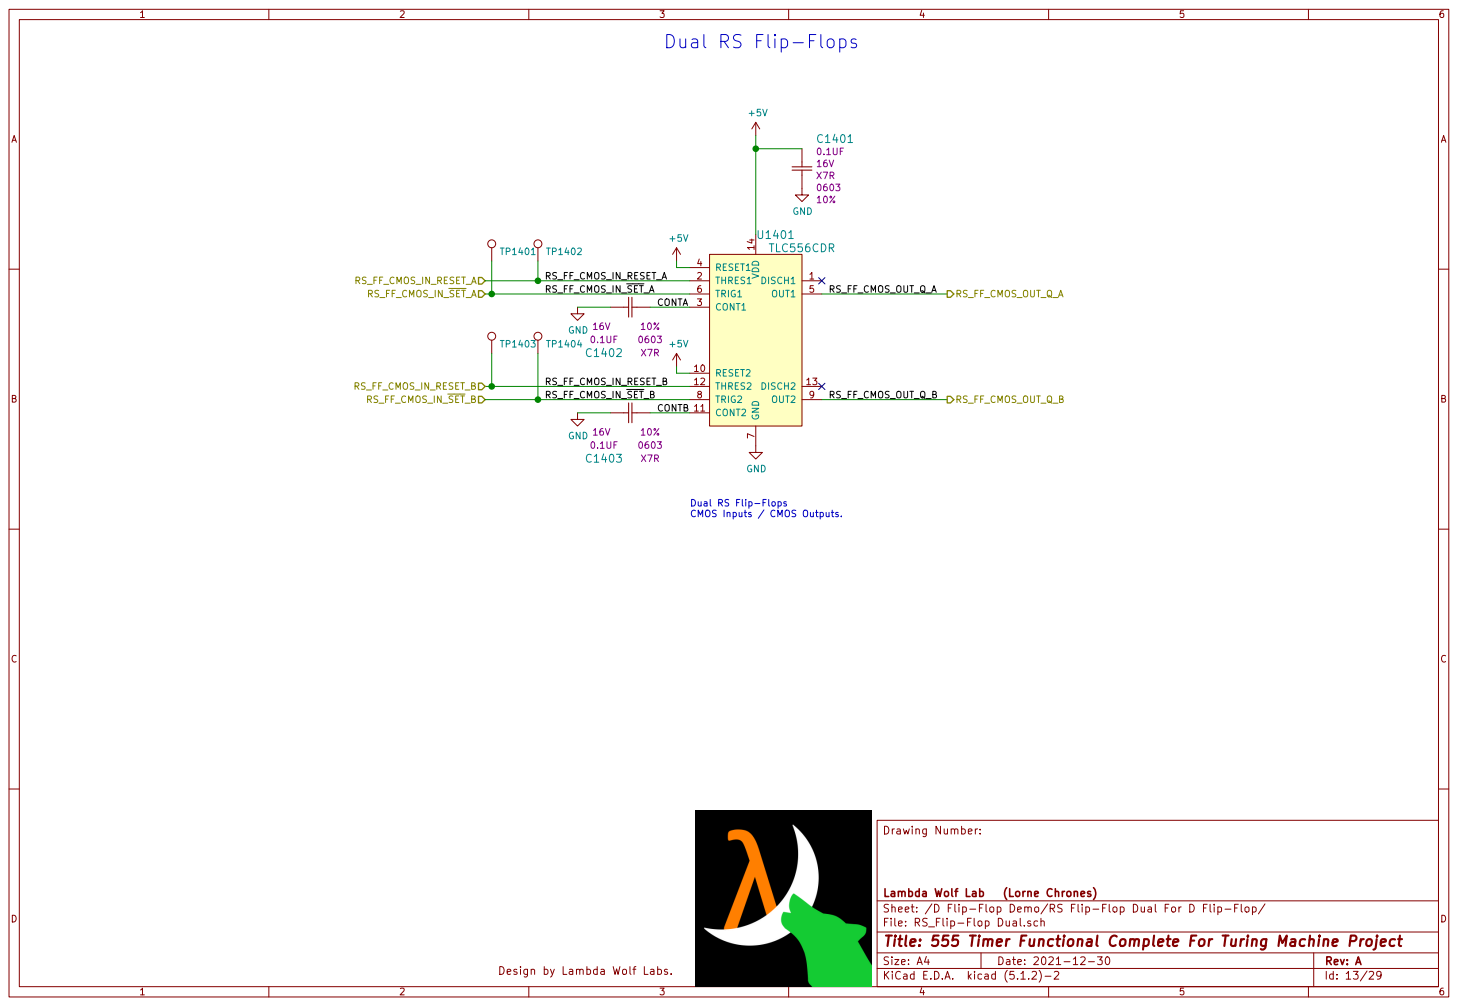
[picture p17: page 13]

Dual RS Flip-Flops

+5V Dual RS Flip-Flops

Sheet: /D Flip-Flop Demo/RS Flip-Flop Dual For D Flip-Flop/
File: RS_Flip-Flop Dual.sch
Id: 13/29 Title: 555 Timer Functional Complete For Turing Machine Project

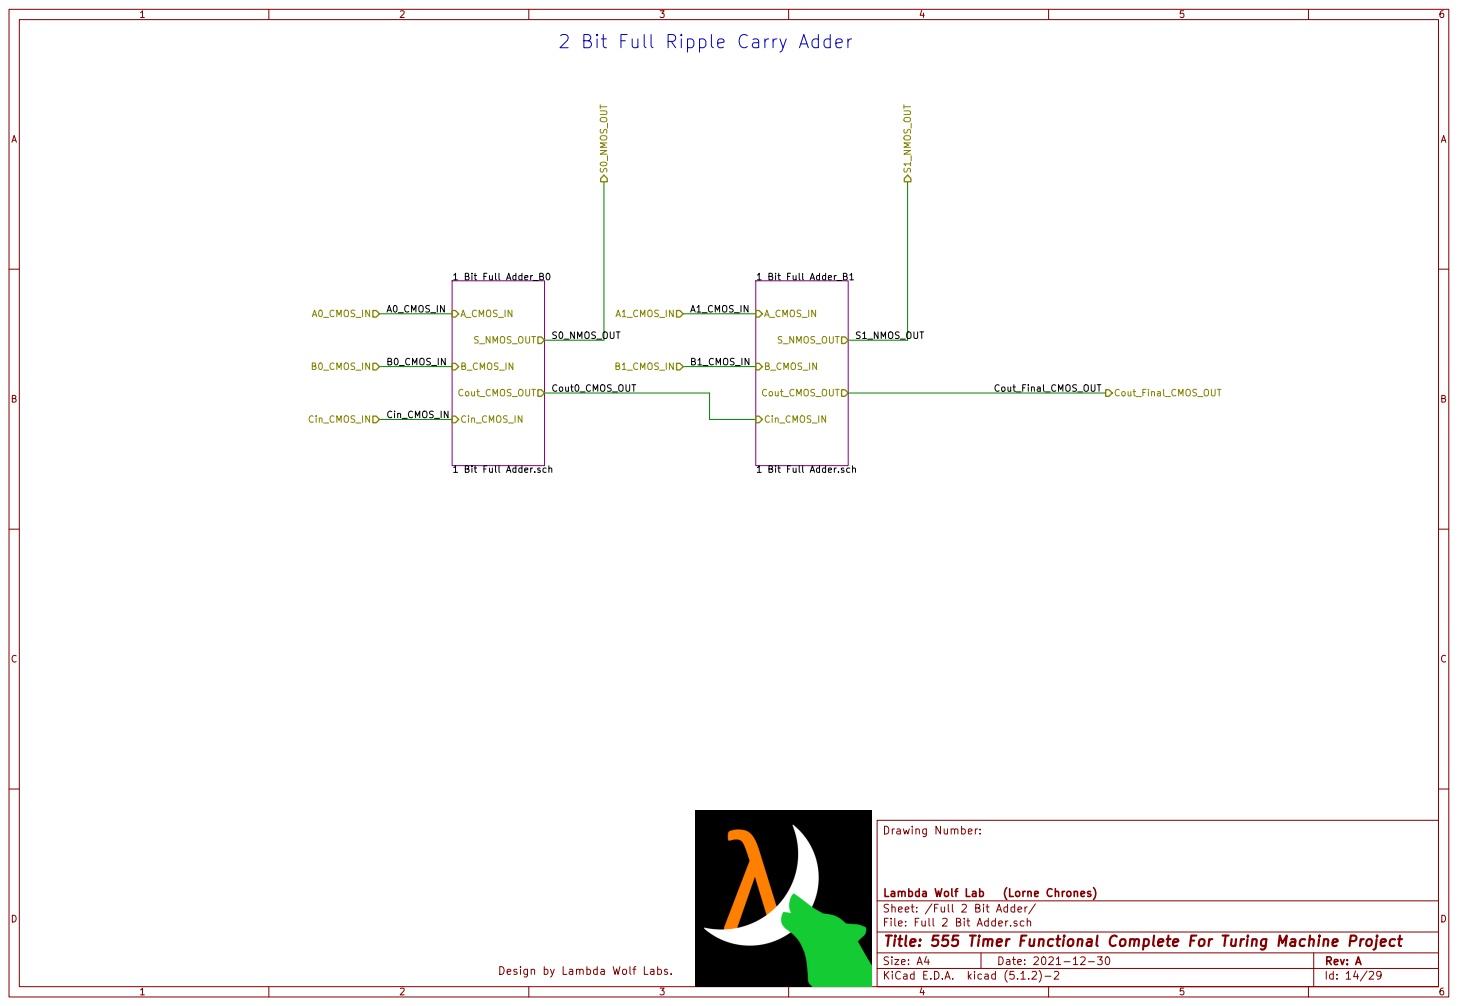
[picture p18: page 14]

2 Bit Full Ripple Carry Adder

1 Bit Full Adder.sch S_NMOS_OUT A_CMOS_IN


Id: 15/29 Title: 555 Timer Functional Complete For Turing Machine Project File: 1 Bit Full Adder.sch Sheet: /Full 2 Bit Adder/1 Bit Full Adder_B0/

AND Gate CMOS Inputs / NMOS Output

Id: 16/29 Title: 555 Timer Functional Complete For Turing Machine Project File: AND.sch Sheet: /Full 2 Bit Adder/1 Bit Full Adder_B0/AND_Adder_A/


Id: 17/29 Title: 555 Timer Functional Complete For Turing Machine Project File: NOR.sch Sheet: /Full 2 Bit Adder/1 Bit Full Adder_B0/NOR_Adder/


Sheet: /Full 2 Bit Adder/1 Bit Full Adder_B0/Inverter_Dual_Adder/
File: Inverter_Dual.sch
Id: 18/29 Title: 555 Timer Functional Complete For Turing Machine Project


+5V NOR Gate CMOS Inputs / NMOS Output

Id: 19/29 Title: 555 Timer Functional Complete For Turing Machine Project File: XOR.sch Sheet: /Full 2 Bit Adder/1 Bit Full Adder_B0/XOR_Adder_B/

Inverter CMOS Outputs Not Used.


AND Gate CMOS Inputs / NMOS Output

Id: 20/29 Title: 555 Timer Functional Complete For Turing Machine Project File: AND.sch Sheet: /Full 2 Bit Adder/1 Bit Full Adder_B0/AND_Adder_B/

+5V NOR Gate CMOS Inputs / NMOS Output

Id: 21/29 Title: 555 Timer Functional Complete For Turing Machine Project File: XOR.sch Sheet: /Full 2 Bit Adder/1 Bit Full Adder_B0/XOR_Adder_A/

Inverter CMOS Outputs Not Used.


Id: 22/29 Title: 555 Timer Functional Complete For Turing Machine Project File: 1 Bit Full Adder.sch Sheet: /Full 2 Bit Adder/1 Bit Full Adder_B1/


AND Gate CMOS Inputs / NMOS Output

Id: 23/29 Title: 555 Timer Functional Complete For Turing Machine Project File: AND.sch Sheet: /Full 2 Bit Adder/1 Bit Full Adder_B1/AND_Adder_A/


Id: 24/29 Title: 555 Timer Functional Complete For Turing Machine Project File: NOR.sch Sheet: /Full 2 Bit Adder/1 Bit Full Adder_B1/NOR_Adder/

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













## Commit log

2022-01-09 Add files via upload
    Added 555 Functional Complete Demo Board schematic Rev A PDF (from KiCAD project)
2022-01-09 Add files via upload
    Added PCBA Demo Board Rev A Gerbers Build Package
2022-01-09 Add files via upload
    Added Demo Board Rev A schematics and PCBA PDF of all the layers from KiCAD
2022-01-09 Add files via upload
    Added propagation times scope shots from Rev A Demo board.
    [FALLSETUP.stp, RISESETUP.stp]
2022-01-09 Add files via upload
    Added Rev A Board and Early Breadboard Photos
2022-01-10 Add files via upload
    Added partslist BOM RevA
    [BOM_RevA_555_Timer_Functional_Turing_Complete_Project.csv]
